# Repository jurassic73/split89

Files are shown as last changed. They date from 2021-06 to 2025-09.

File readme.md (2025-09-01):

# split89 keyboard - a 3d printed 89 key split TKL keyboard base powered by ATmega32U4 Pro Micro controllers with QMK Configurator support.  

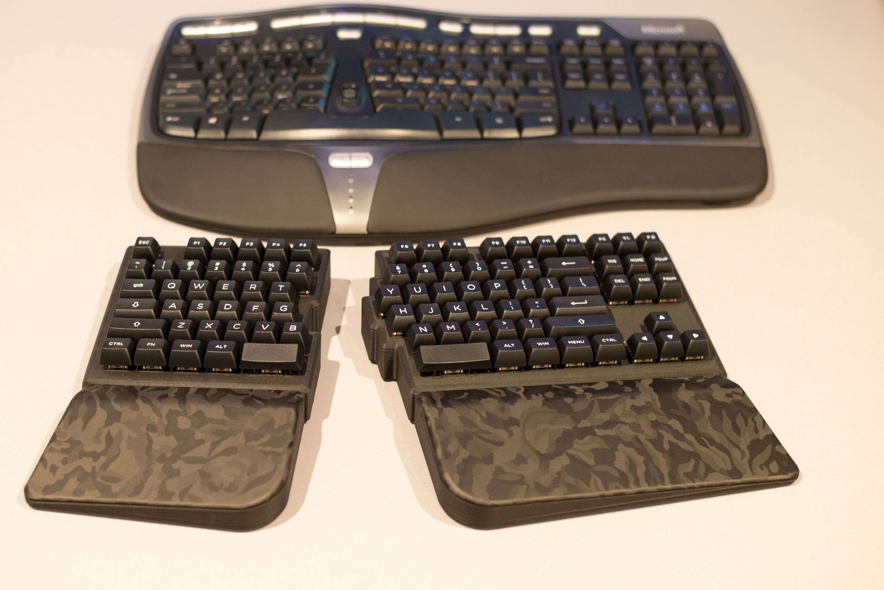
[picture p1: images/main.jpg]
  

This keyboard build was inspired by the Microsoft Ergonomic 4000 keyboard I used for roughly 12 years or so.  I broke my left wrist twice over the years so an ergo keyboard is a must for me to type comfortably all day long else my left wrist starts to burn after a few hours of typing on a regular keyboard.  This is a real bummer since there are so many amazing keyboards out there.  I could not find a split TKL like this layout so I designed one.  I started designing this on Dec 4th, 2020 and built my first version in June 2021. This has a 6° tent and a 3° incline.  I designed this to sit as low as possible with these angles on a table.  One key switch is actually in a recess in the baseplate with a few mm of material below it.

YouTube - Overview Build Videos<br>
[Part 1](https://youtu.be/i7usy5cnMP0) [Part 2](https://youtu.be/8Tm1rYtXKhw) [Part 3](https://youtu.be/rSSixBk8nNw)

The left half has an extra key on the bottom row(vs standard TKL) so you can shift to other layers for more functionality.  The [default keymap below](#programming-the-controllers) illustrates this.  Verify the keycaps you shop for has eight 1.25u keys for this row. You'll also need to source 2.25 and 2.75 space bars. Reversed shift keys often work well in this position and provide your thumbs with a more agreeable landing surface angle.

QMK Configurator support means you can create a custom firmware for this keyboard with your own keymaps/layers or simply download the existing keymap firmware via the [QMK Configurator](https://config.qmk.fm/#/handwired/split89/LAYOUT) page.

Given you have all tools required, you can build this keyboard for roughly $120 in materials minimum that I can find.  My builds were average $150-$200 or so in materials.

What if you don't have a 3d printer?  You may have options... there are print services out there, the [3Dprintmything subreddit](https://www.reddit.com/r/3Dprintmything/) may be of help or your local maker space or check with friends that print(if you know someone).  Rates can vary quite a bit so shop around.  This is no quick print, it takes roughly 77 hours to print all parts.  There are specifics below you'd want said printing help to view before slicing to ensure your parts are printed as needed.  Of course this could be the project that justifies the purchase of a printer of your own! :)

If you're stuck with what to go with regarding colors and materials(there are a ton of options out there for your components), check out my monochrome material list towards the bottom of this page.  Hard to go wrong with a black/white keyboard scheme. Also check out the [Printables split89 Makes](https://www.printables.com/model/75599-split89/comments) for inspiration.

If you wish to redesign/modify any bit of this keyboard, a STEP file ( [split89.step](https://github.com/jurassic73/split89/blob/main/split89.step) ) has been added to the repo for you to download and edit with your CAD software.

A request from me... If you end up building this keyboard, please share your build here as a make! [prusaprinters.org split89](https://www.prusaprinters.org/prints/75599-split89)  Builders have taken customization options in directions I never thought about and it's awesome to see them customize them to their liking. I was happy with the result of this build for my own use and put this document together to share this design and hopefully inspire/help others looking to build a split TKL.  I've built four of these keyboards so far and learned things to adjust and document to refine this build document and videos to dump as much knowledge as I could so the only thing holding back a builder is time and the desired to build. :) Seeing your build would be awesome.

**External Links**  
[QMK Configurator](https://config.qmk.fm/#/handwired/split89/LAYOUT) - keymap/firmware generator  
[prusaprinters.org](https://www.prusaprinters.org/prints/75599-split89)  

**Table of Contents**  
[Bill of Materials](#bill-of-materials)  
[Tool suggestions](#tool-suggestions)  
[Assembly](#assembly)  
1)  [Print keyboard pieces](#print-keyboard-pieces)  
2)  [Install keyswitches and stabs](#install-keyswitches-and-stabs)  
3)  [Prepping the diodes](#prepping-the-diodes)  
4)  [Installing the diode rows](#installing-the-diode-rows)  
5)  [Installing the column wires](#installing-the-column-wires)  
6)  [Wiring the controller, reset button and TRRS jack](#wiring-the-controller-reset-button-and-TRRS-jack)  
7)  [Programming the controllers](#programming-the-controllers)  
8)  [Installing the base plates](#installing-the-base-plates)  
9)  [Wrap the wrist bases and rests](#wrap-the-wrist-bases-and-rests)  
10) [Mount the wrist bases and rests](#mount-the-wrist-bases-and-rests) 
11) [Install rubber feet](#install-rubber-feet)  

**My Personal Builds**  
[Keyboard Pics](#my-personal-build)  
[Main Hardware](#my-personal-build-main-hardware)  
[Tools](#my-tools)  
[GMK Info](#gmk-info)  

# Bill of Materials  
  * 3d printed components in [3d_printing_stl_files](https://github.com/jurassic73/split89/tree/main/3d_printing_stl_files) directory
    **See print notes below! ( [Print keyboard pieces](#print-keyboard-pieces) ) Critical for successful printing!** <br>
    **Print one of each:**  
      split89_electronics_plate_left.stl  (microusb or usbc)
      split89_electronics_plate_right.stl  (microusb or usbc)
      split89_left_body.stl  
      split89_left_body_base.stl or split89_left_body_base_no_pillar.stl *  
      split89_left_wrist_base.stl  
      split89_left_wrist_pad.stl  
      split89_right_body.stl  
      split89_right_body_base.stl or split89_right_body_base_no_pillar.stl *  
      split89_right_wrist_base.stl  
      split89_right_wrist_pad.stl  
    **Print two of each:**  
      split89_arduino_brace.stl  (microusb or usbc)
      split89_reset_button_brace.stl  
      split89_trrs_jack_brace.stl  
        \* Note - there are two versions of the base plates.  The original has bolt holes and a partial pillar to connect to the body in the middle of the large surfaces to couple the base to the main body surface for a tighter sound.  I added base plates that are void of these pillars/bolt holes which decouples the two large surfaces in the middle for a slightly deeper typing sound.  I prefer the latter but a user can try both to see which they prefer.

        \* Note - there are two versions of electronic plates. USB-C and micro USB. There are also two versions of the Arduino brace.

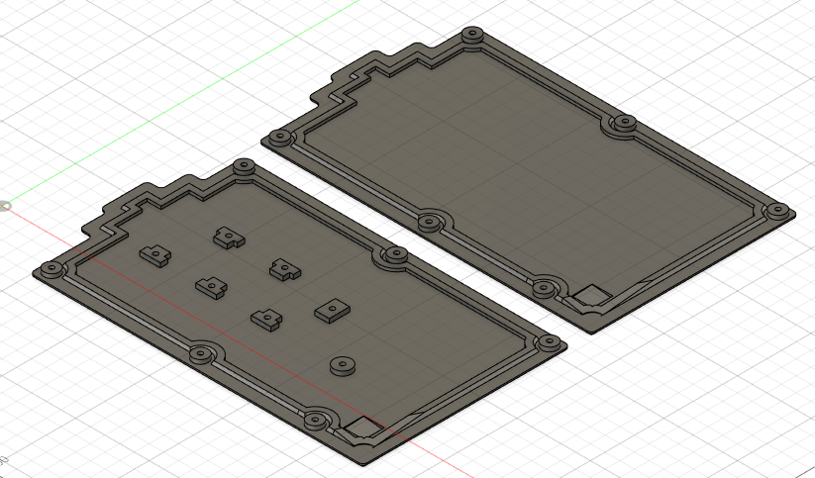
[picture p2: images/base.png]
      
    
  * (2) Pro Micro ATmega32U4 USB-C or USB micro<br>
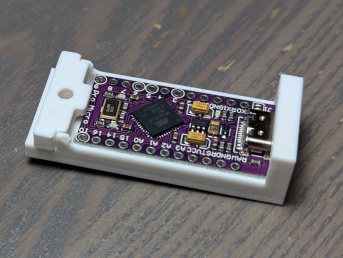
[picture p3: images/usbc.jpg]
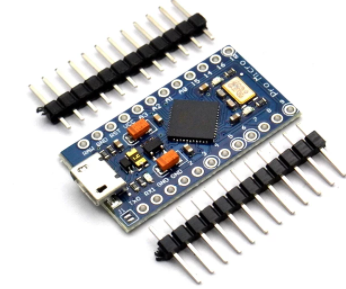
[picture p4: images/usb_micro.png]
     

      A few places to purchase<br>
      * USB-C - [Aliexpress](https://www.aliexpress.us/w/wholesale-pro-micro-usbc-arduino.html)
      * USB Micro - [EBay](https://www.ebay.com/sch/i.html?_nkw=pro+micro+atmega32u4)
      * USB Micro - [Aliexpress](https://www.aliexpress.com/af/atmega32u4.html) (usually cheaper if you have time to wait for slower shipping)

  * (1) 3.5mm TRS or TRRS male to male cable - [EBay](https://www.ebay.com/sch/i.html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) - only three pins in the TRS positions are being used so TRS or TRRS are acceptable to use for connectivity between the halves.  There are some with two 90° plugs if desired for a compact fit. T = tip, R = ring, S = sleeve.
  * (2) 3.5mm TRS/TRRS breakout boards - [Aliexpress](https://www.aliexpress.com/wholesale?SearchText=trrs+audio+socket+breakout) [Amazon](https://www.amazon.com/s?k=trrs+board&Go=Search+Amazon)
  * (1) 2k-10k resistor - [Aliexpress](https://www.aliexpress.com/item/32952657927.html) - a resistor value somewhere in the 2k to 10k range will work.
  * (2) Tactile Micro vertical mount switch (6mmx6mmx8mm total height / 4.5mm button height) - [Aliexpress](https://www.aliexpress.com/item/4000543708838.html?spm=a2g0s.9042311.0.0.27424c4dCLLkyk)
  * (1) USB-C or USB micro cable - only one side needs to be connected to your computer so only one USB cable is required.  I like the magnetic disconnect USB cable I listed towards the bottom of this document.  Make it easy to disconnect the USB cable when needed.  The cable needs to be connected to the keyboard with the LED on the cord plug facing upwards for proper connectivity.
  * (89) key switches - [NovelKeys](https://novelkeys.xyz/collections/switches/products/gateron-switches?variant=37302529851559) - example switch to use - I'm a fan of linear switches.  If you're not sure which key switch type you'd like, there are [key switch testers](https://www.amazon.com/s?k=key+switch+tester) out there to help you make your decision.
  * (6) 2U plate mount key switch stabilizers [Amazon](https://www.amazon.com/gp/product/B096JVL2MQ/) - [Aliexpress](https://www.aliexpress.com/item/1005001543613992.html) - buy a few smaller sets or the one for the 104 keyswitch board to get the (6) required 2U stabs.
  * (87) key caps - [Key cap List](http://www.keyboard-layout-editor.com/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'&_w:2.25%3B&=Enter%3B&@_w:2.25%3B&=Shift&=Z&=X&=C&=V&=B&_x:2.75%3B&=N&=M&=%3C%0A,&=%3E%0A.&=%3F%0A%2F%2F&_w:2.75%3B&=Shift&_x:1.25%3B&=%E2%86%91%3B&@_w:1.25%3B&=Ctrl&_w:1.25%3B&=Fn&_w:1.25%3B&=Win&_w:1.25%3B&=Alt&_a:7&w:2.25%3B&=&_x:2.75&w:2.75%3B&=&_a:4&w:1.25%3B&=Alt&_w:1.25%3B&=Win&_w:1.25%3B&=Menu&_w:1.25%3B&=Ctrl&_x:0.25%3B&=%E2%86%90&=%E2%86%93&=%E2%86%92) - most standard keycap sets will work fine but ensure they have eight 1.25u keycaps.  Some only have seven.  I'm a big fan of the [AKKO keycap sets](https://en.akkogear.com/store/keycap/) in ASA profile which is like a cherry MX but slightly sculpted(Much less than SA profile) in both directions vs cylindrical.  They have more color sets on their site vs Amazon.  Amazon has a good return policy if you want to order them and just see them in person to see if you like them.
  * (2) space bar keys - 2.25u / 2.75u - As noted above, beyond the standard keycaps, you'll need to either source 2.25u/2.75u space bars(which can be tough) or just use shift keys for your space bars (2.25u and 2.75u) in reverse orientation.  Most keycap sets don't come with 'extra' space bar caps so I like to use these blank shift keys for space bars. The face angle of these shift caps, installed in reverse orientation, is really agreeable for your thumb to land on. They look odd at first, but once you try them in this orientation, I feel you will not want to change them.
  
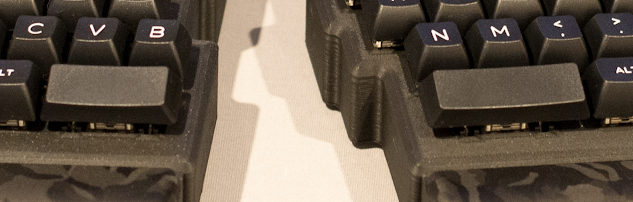
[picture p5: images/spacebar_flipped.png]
    
  
    They are only available in ABS so they will take a little shine over time but they're a comfortable compliment to my AKKO ASA sets and come in enough colors to get something close or at least neutral in color vs your primary keycap set.  They're also the most reasonable cost I've found out there at $2.50 per individual cap.  WASD can custom print items on your caps but I found that print wears off in time so I stick with blanks from them.
  * Wire - 6 color pack on [Amazon](https://www.amazon.com/gp/product/B07V1D82HM/) - 24AWG pre-tinned wired - color helps you keep track of what's where.  Solid core and pre-tinned as well so soldering is easier. 
  * (89) 1N4148 Diodes - 100ct pack - [Aliexpress](https://www.aliexpress.com/af/1N4148-do%25252d35.html) - [Ebay](https://www.ebay.com/sch/i.html?_nkw=1N4148++do-35)  
  * M3 Hardware  [Amazon](https://www.amazon.com/s?k=m3+hardware) - [Aliexpress](https://www.aliexpress.com/item/10000150053486.html)  
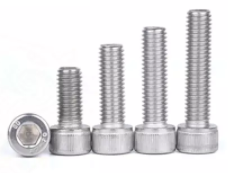
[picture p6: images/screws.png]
    
    (6)  20mm  
    (34) 10mm  
    (5)  8mm  
    (3)  6mm  
    (6) washers  
    (6) nylock nuts  
  * Car wrap vinyl - [metrostyling.com](https://metrorestyling.com/pages/3m-vinyl-wrap) or [Ebay](https://www.ebay.com/sch/i.html?_nkw=carbon+fiber+vinyl+wrap+3M) - for covering wrist rest pad pieces.  The 3d printed surfaces are rough and can hold stuff so putting this on makes them a more comfortable contact surface and easy to clean.  There are videos for applying with a heat gun/hair dryer to soften at the corners to stretch around them for a smooth finish.
    (2) 8 1/2" x 11" sheets
  * (18) Rubber feet - [Amazon](https://www.amazon.com/gp/product/B00K6RZ9Q2/) - 144 pack

# Tool suggestions  
  These tools are not required but certainly make the build easier and come in handy on most electronics projects
  * [Micro flush cutters](https://www.amazon.com/s?k=micro+flush+cutters) - these not only cut wire but have one side flattened so you can cut items flush with a surface like on the back of the Pro Micro where some wires may be sticking out beyond the solder.
  * [Tweezers](https://www.amazon.com/s?k=electronics+tweezers) - there are a ton of options out there.  Something with a long narrow end and serrations for grip are very handy to move things around or hold them in position while soldering.
  * [Blue tack](https://www.amazon.com/s?k=blue+tack) - this stuff is typically used to mount things on other things like cardboard or paper but a chunk works great to hold things in position while you solder.  Just don't heat up objects too long or it can get a little sticky.
  * [Vice](https://www.thingiverse.com/thing:2064269) - great tool to have in your toolbox for holding small items like the TRRS and Pro Micro boards when soldering.

# Assembly

### Print keyboard pieces

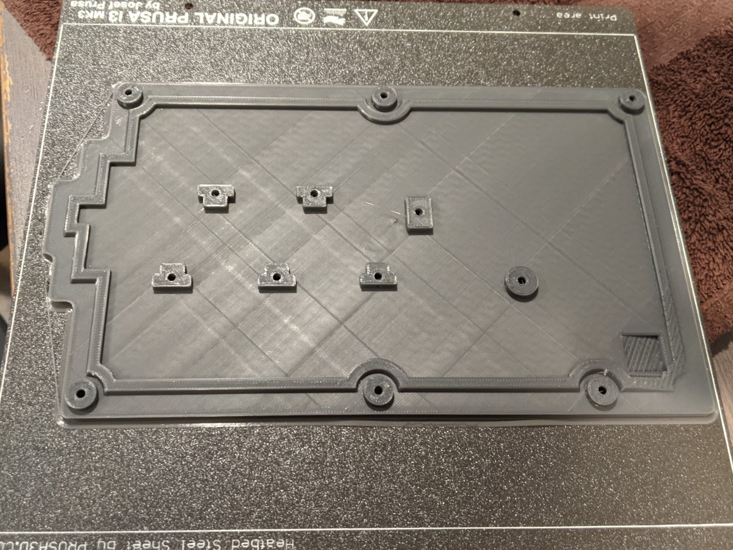
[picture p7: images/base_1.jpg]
  

  I've built four of these keyboards now.  One using SunLu Gray PETG and three using Eryone Matte PLA.  PETG is less rigid vs PLA and holds it's shape better over time under pressure like a bolted assembly vs PLA however this Matte has performed well as well and I would easily recommend it along side PETG and it prints easier.

  All pieces were printed using .2mm layer height.  All .stl files should be printed as oriented.  No supports with exception of the wrist rests which use a bit of support material but I found it was the best orientation for the cleanest contact surface possible.

  You should only need one roll of filament for the exposed color pieces.  That is, if you're covering your wrist pads with vinyl, you should be able to print your wrist bases, bodies, body bases and electronic plate parts out of a single roll of filament and your wrist pads with whatever other color since you're covering them up with vinyl.

**Keyswitch Hole Test Print**

I've added a split89_keyhole_test_print.stl model with a 13.9mm square hole.  Configure your slicer per the below notes, including EFC settings, and print this test piece to ensure your key switch fits correctly in this hole before printing the larger pieces.  Test fit that your key switch installs but isn't deformed or overly tight.  When you look at this printed model, the inside dimension should be 13.9mm square, and the interior walls should be flat, bottom to top, with no bulge/lip(which would indicate an Elephant foot is present).  If the interior walls are flat, bottom to top, you should be ready, with these settings, to print your larger pieces.

**Body Piece/Base Print Notes**

    split89_left_body.stl  
    split89_left_body_base.stl or split89_left_body_base_no_pillar.stl  
    split89_right_body.stl  
    split89_right_body_base.stl or split89_right_body_base_no_pillar.stl  

  **Surface Texture** - The body pieces have the most visible surfaces and I preferred to use a textured print plate as that textured surface hides print lines really well and if you scratch it over time, the texture can kinda hide that wear.  
  
  **Surface Prep** - Unless you know your pieces will stick well, wash your build plate before printing each of these with Joy or Dawn dish washing soap.  This seems to remove all PLA residue for me and ensures a clean print.  You're gonna be staring at this top surface of the body the most, ensure you get a good print with good adhesion.
  
  **PLA** - print bed at 60C helped ensure minimum warping.  I printed at 215C nozzle temp with the matte PLA.
  
  **PETG** - I used the default settings - I had some lifting in the corners.

  **Perimeter** - default 2 or 5 - I changed the perimeter count to five from the default 2 in my slicer for the body pieces as well.  I wanted heavier/denser pieces so my bases didn't sound so hollow.  

  **Brim** - do no use - not needed with good bed adhesion and will cause issues as you need to disable Elephant Foot Compensation(EFC) so the brim attaches to the body correctly(currently the state with Prusa Slicer) but disabling EFC will cause major issues with your key switch holes(see next note).

 **Elephant Foot Compensation** - leave enabled/required  The designed printed key switch holes are 13.9mmx13.9mm.  A key switch is 14mmx14mm.  This .1mm designed difference creates a nice friction fit to secure the switch without deforming it.  Without EFT, any bit of resulting elephant foot deformation interferes with this design and can affect switch operation.  I found this out the hard way during one of my initial prints by disabling EFC. My switches were either too tight when installed and they were deformed and it bound up the stem or the elephant foot was so much in one area of one of the bodies, that I could not insert my switches.  **Keep EFC enabled.**
  
  **Support** [easy to remove support settings](https://projects.ttlexceeded.com/3dprinting_techniques_removable_supports.html) - supports for this build are only needed for wrist pad pieces.  The supports can be very tough to remove easily/cleanly from wide surfaces however I use the settings in the link.  The supports,created with these settings, remove relatively easily/cleanly without much effort.
 
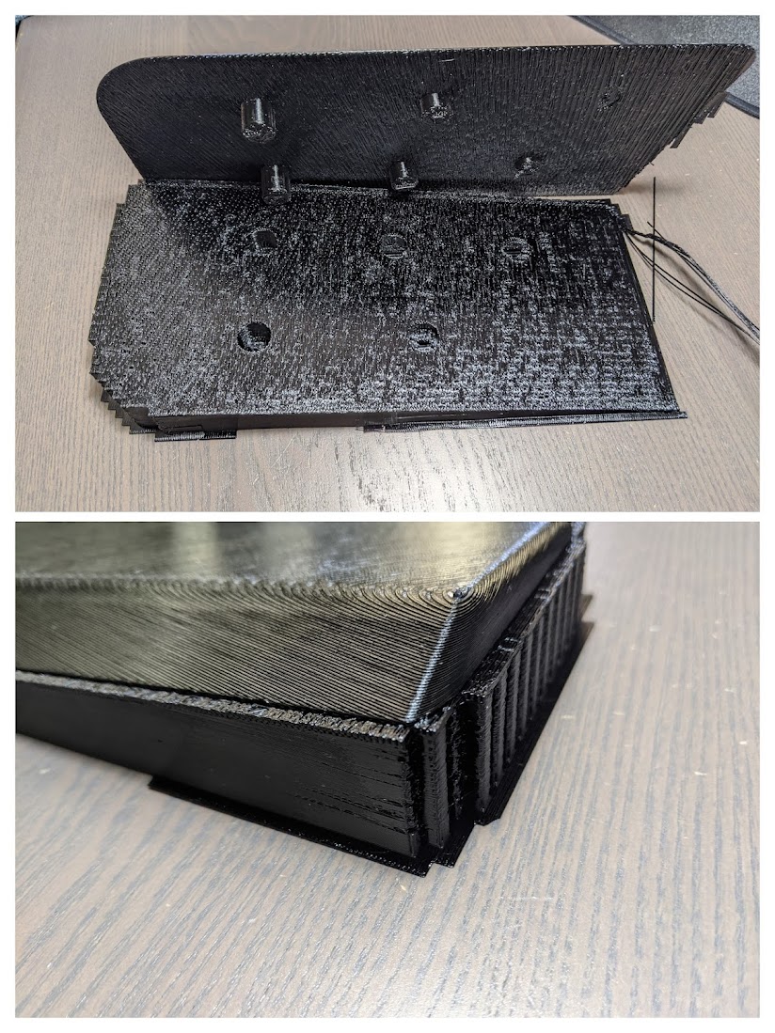
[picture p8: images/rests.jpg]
 
 
 The remaining pieces for the wrist pads/bases and electronics plates I printed using the default Prusa slicer settings for PLA or PETG respectively.
  
### Install key switches and stabs

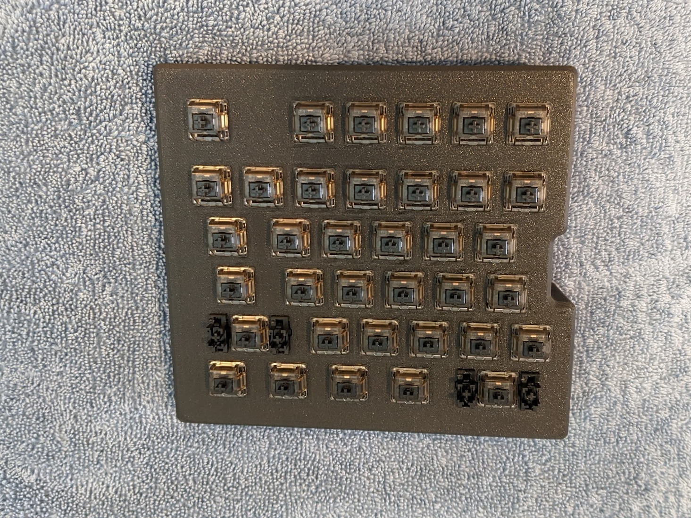
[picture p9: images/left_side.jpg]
  

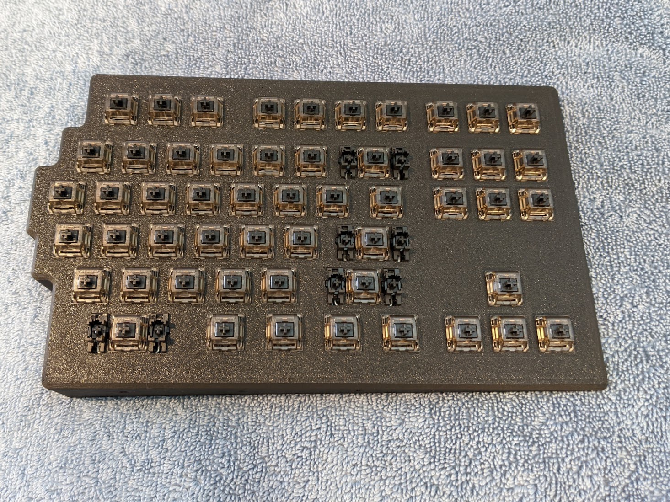
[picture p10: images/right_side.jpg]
  

  This keyboard has 13.9mm square holes for the key switches.  The key switches should press into place firmly.  The stabilizers insert and kinda rotate into their position as they are fully seated.  I took the time to disassemble and lube my key switches using Super Lube prior to installation.  Also added lube to my stabs.  This is not required but the few hours you put in to lubing your switches will be noticeable over many hours of use.  There are many videos out there on how to do this.

### Prepping the diodes

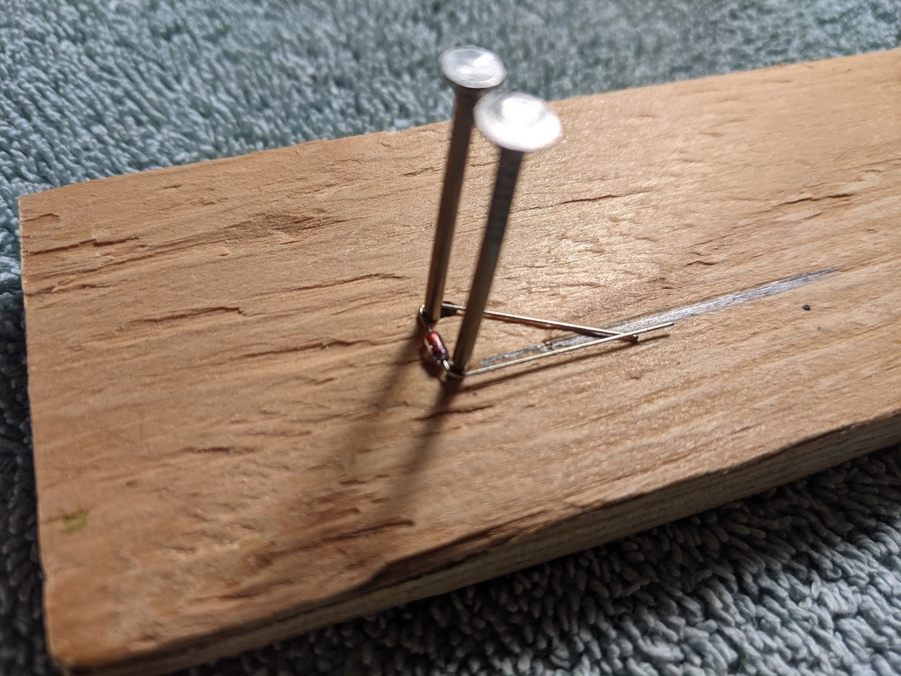
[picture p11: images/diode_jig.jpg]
  

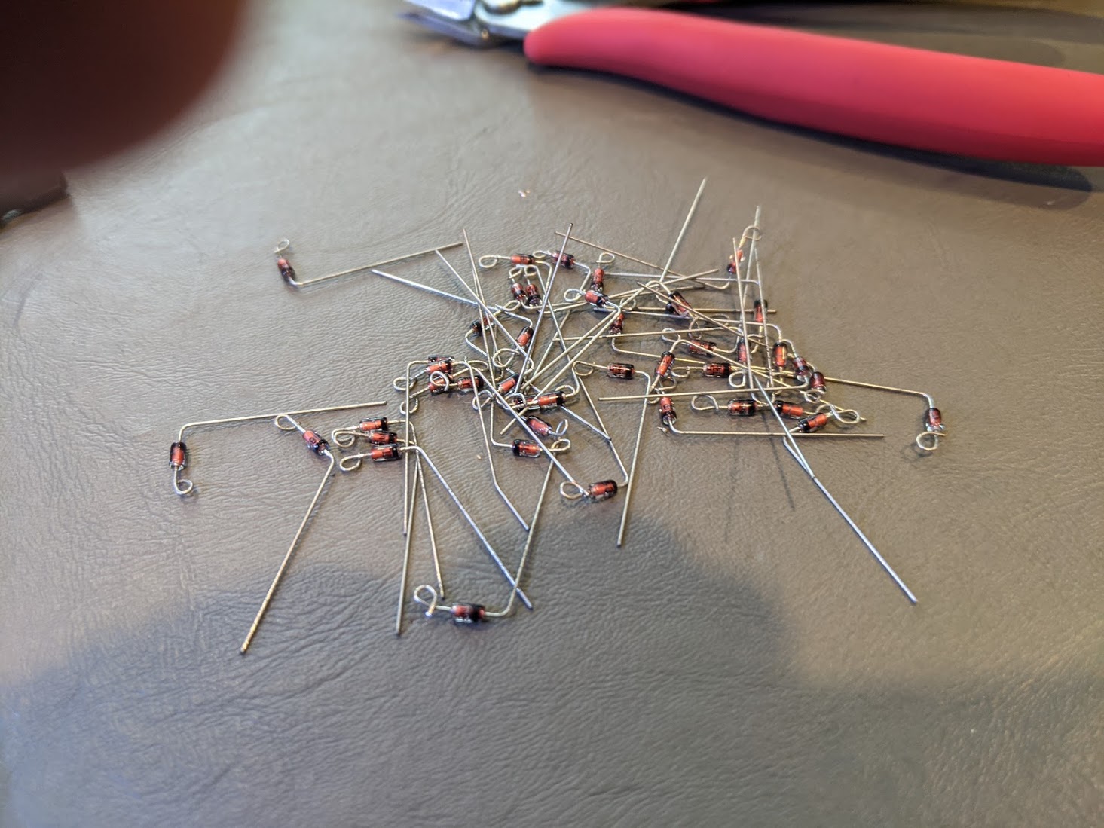
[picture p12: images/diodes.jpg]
  

  For an easier installation and cleaner final result, I opted to put a few nails in a board(1 cm apart center to center) with a line perpendicular to the nail's alignment, to help me put consistent 90 degree bends in them at the right lengths.  The bottom will get a 90 degree bend. The top gets a 90 as well but then you'll use a pair of needle nose pliers to make a loop.  This loop will go over one of the legs of the switches for easier soldering.  Ensure that you have the black marked end of the diode facing the 90, not the loop.  This is critical for your keyboard to operate.  One of my diodes was backwards and the key at that location would simply not work til I fixed the diode orientation.

### Installing the diode rows

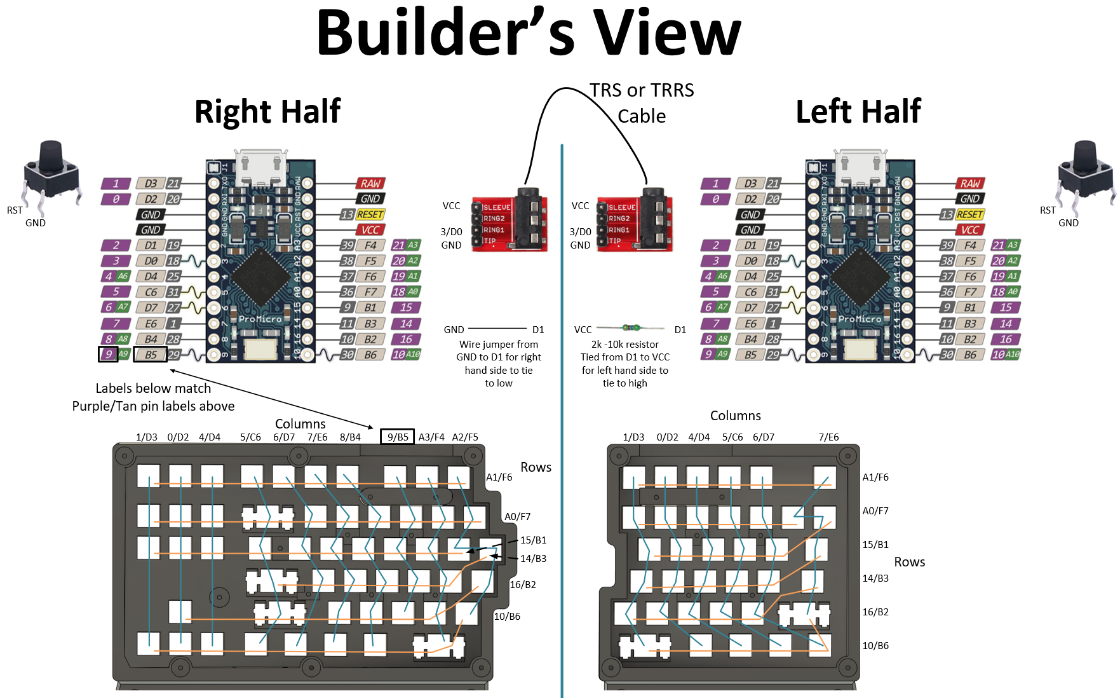
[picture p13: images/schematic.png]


  Each key switch requires a diode.  I installed these one row at a time.  I would put all diodes in place for the row I was soldering.  The diode at the far right column had it's 90 leg snipped short.  Once all are laid in place, solder from left to right.  I used the cut off legs to cover the distance between the keys in rows that were further apart for appearance.  You could just jumper these spans with wire as well.

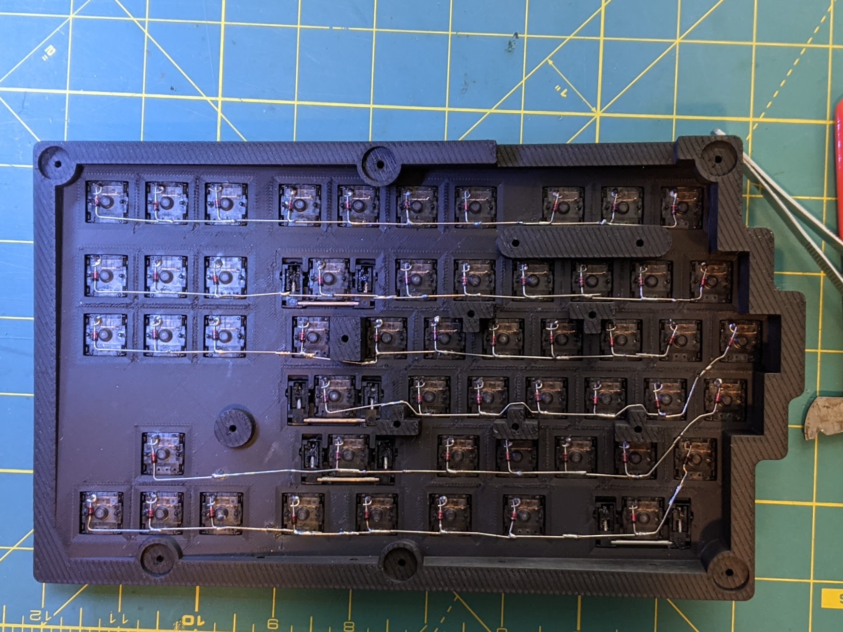
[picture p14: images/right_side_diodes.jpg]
  

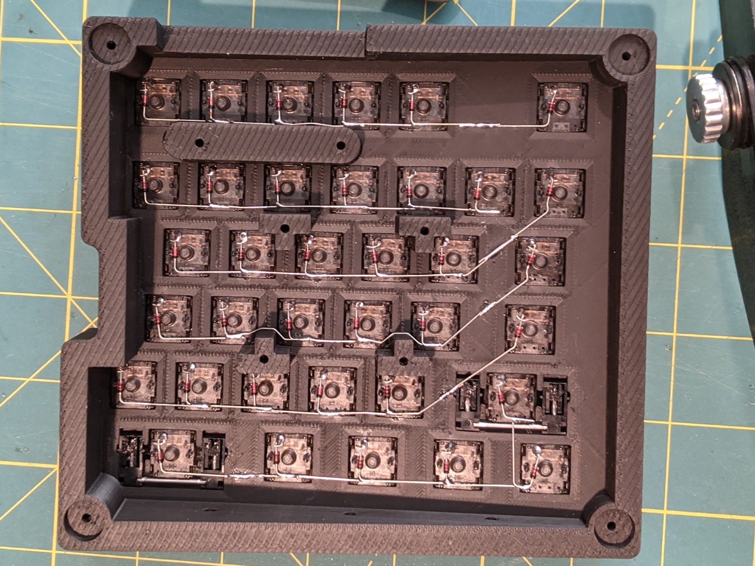
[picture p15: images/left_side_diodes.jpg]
 

### Installing the column wires

  Per the diagram, using insulated wire, you will solder the 5-6 pins per column together.  To do this, I would cut 8" pieces at a time.  Easiest way is to just pull all six colors at once and cut them together.  Remove 1/2" of insulation from one end and make a loop similar to the diodes.  Put this on the pin of the switch at one end of the column.  Next, you'll need to figure out where you need to expose the wire.  I'd put the wire on the first pin and then bend the wire where the next pin is located.  I used a set of wire strippers(which you can set how far they close) to cut the jacket(not the wire) and then, holding the looped end, pull the insulation a bit to expose 1/4" of wire.  I'd repeat threading the wire in place to find where to cut and eventually end up with a piece of wire with gaps where I needed to solder.  Some folks use an x-acto knife to open the wire insulation where needed.  Others use a soldering iron to just melt the jacket away.  At any rate, you'll build these column wires and solder them into place per the diagram.

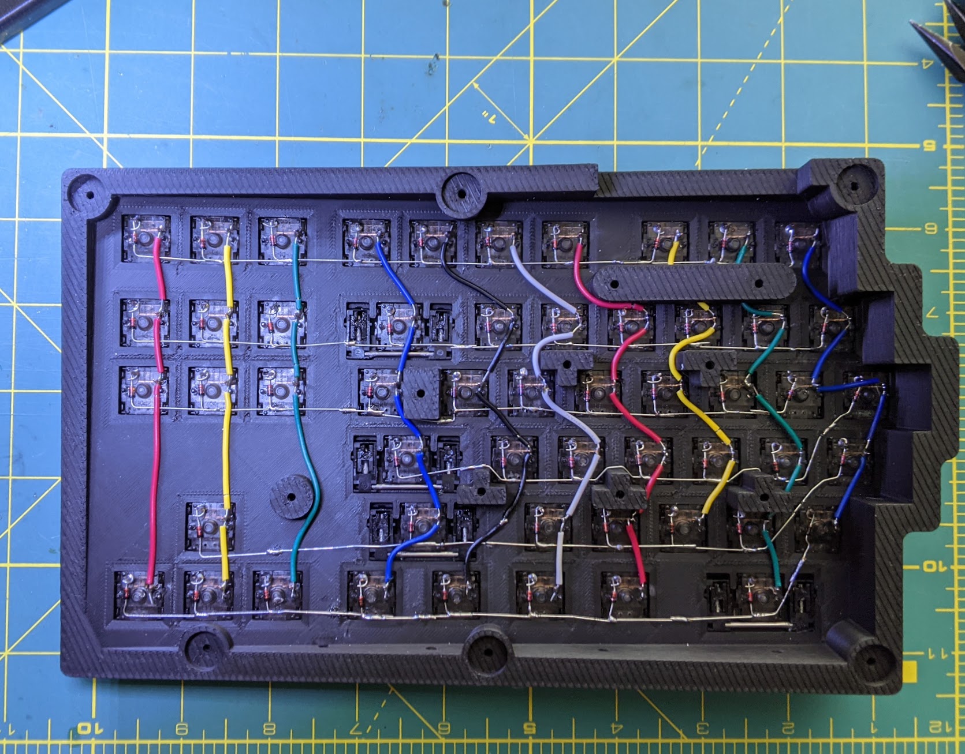
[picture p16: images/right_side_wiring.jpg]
  

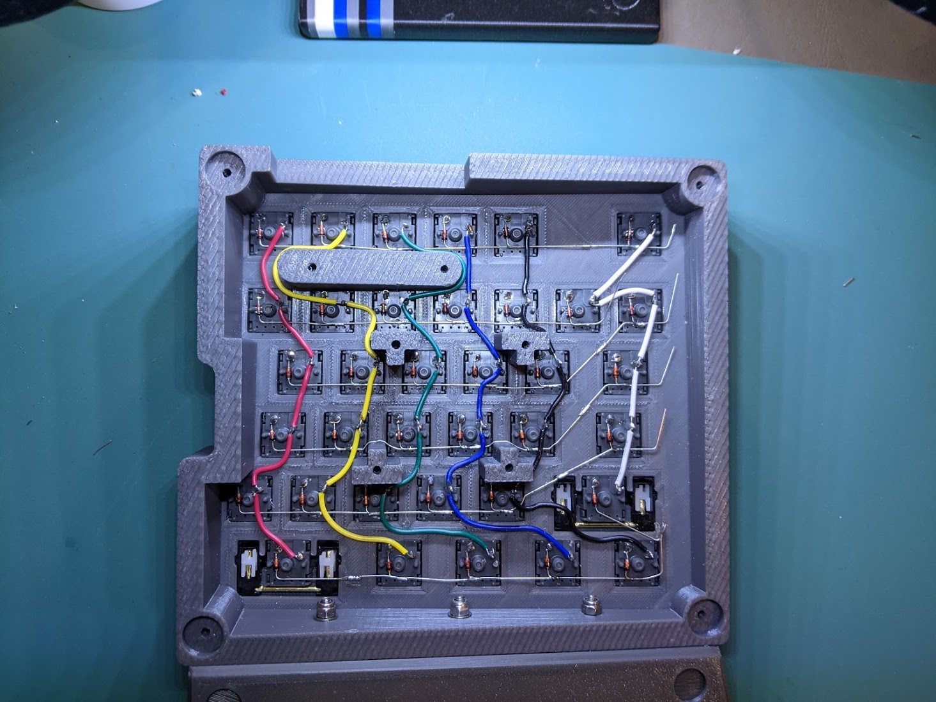
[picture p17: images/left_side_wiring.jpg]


### Wiring the controller, reset button, TRRS jack, jumper and resistor
  
  Note: keep good length wires to the reset switch, TRRS jack plate and off to the matrix from the controller in such a way that you can route them to lie flat enough so you can properly install the base plate.  Note the base plate has a rim as well.  If the wires are stacked too high, you won't be able to install the base plate correctly (made this mistake myself and had to install longer wires so they could route properly to lay flat).

  The tactile reset switch is not directional.  i.e. the two wires connecting to them just need to connect to two contacts that come out the same side of the switch.

  I would highly recommend putting all jumpers required, in place on the pro micro, before mounting the pro micro on the electronics plate.   If the pro micro boards are a snug fit, you can either sand or scrape the edge of the PCB (exposed edge next to the pins) lightly and then try refitting.  I found that most of my boards installed fine while I had two that had somewhat rough edges which didn't allow them to slide in to place.  After scraping the edges a touch, they slid in to place on the electronics plates fine.

  **NOTE**: if you find the USB-C board slides after the brace is in place, put a piece of electric tape between the board and brace to make up the difference. There may be up to 1mm variation in your USB-C board length.

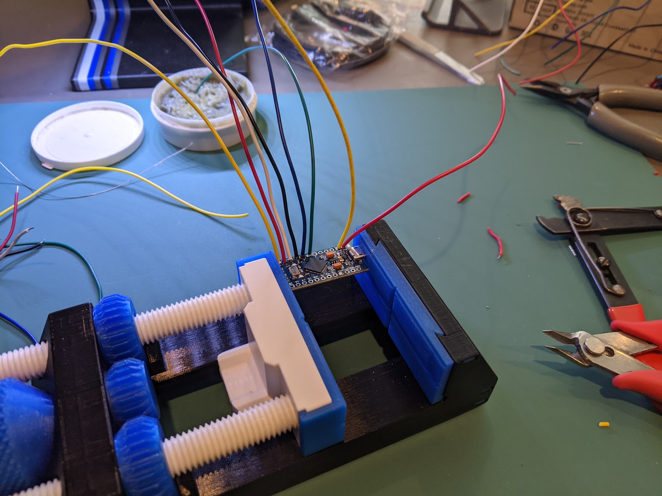
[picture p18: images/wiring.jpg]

  
  Also, note which plate goes with with which controller, right or left.  They are specific to each side.  The right side has more wires.  Pre-wiring the controllers will make for an easier and cleaner installation.  I tinned all of the pins on the controller I'd be using ahead of time.  The pre-tinned wire drops into place nicely when these tinned pins are reheated.  
  
  The pins on the pro micro need to be connected to the respective rows and columns of the keyboard matrix.  They can be connected at any point of the column or row.  On the row connection, connect to the common connection across all diodes, not on the switch side of a diode.
  
  I cut 8" wires again, six at a time, to connect to my pro micro and then tied them to the matrix as you can see below.  I had some scrap left over but it's worth it for ease of install to ensure everything can reach with slack to give you routing options.

  There is a jumper and resistor that need to be installed on the pro micro boards to tie pins to high and low.  This is done so the pro micro boards know which they are expecting to be wired to, to apply the firmware accordingly to what you've wired out(left side or right side).  The wire jumper ties it's pin low to ground(right half).  The resistor ties it's pin high to VCC(left half).  

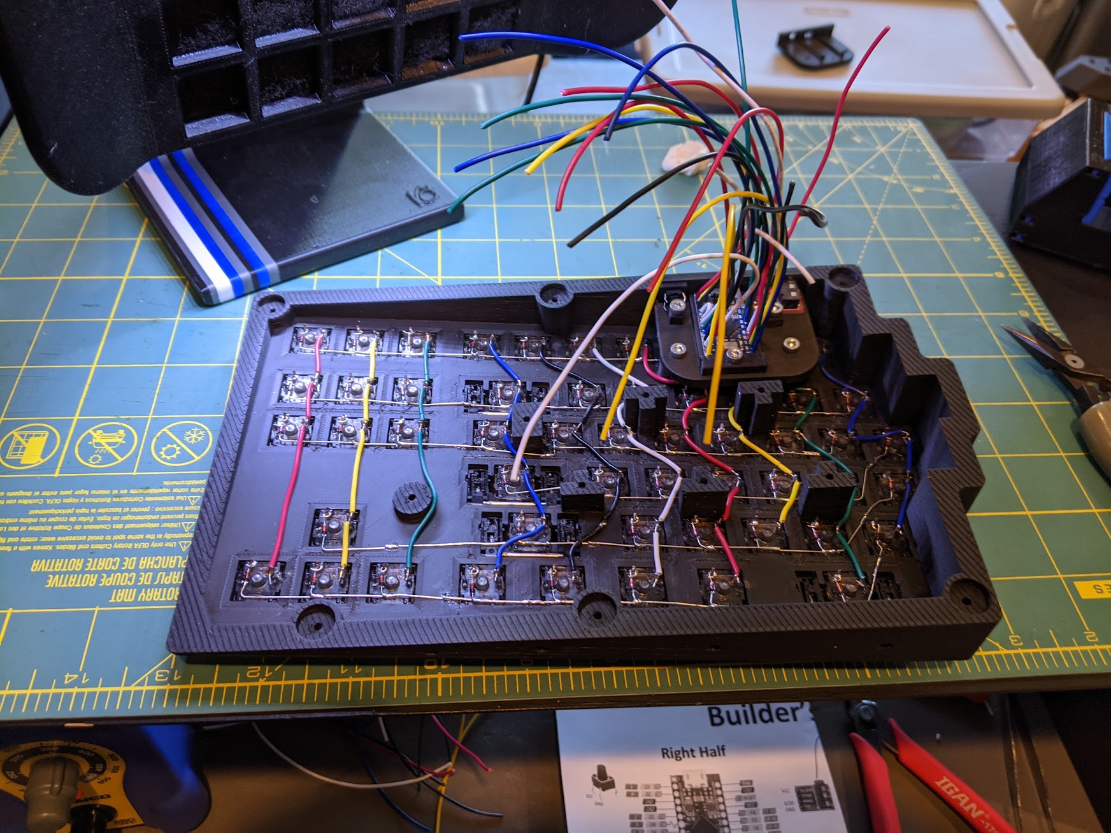
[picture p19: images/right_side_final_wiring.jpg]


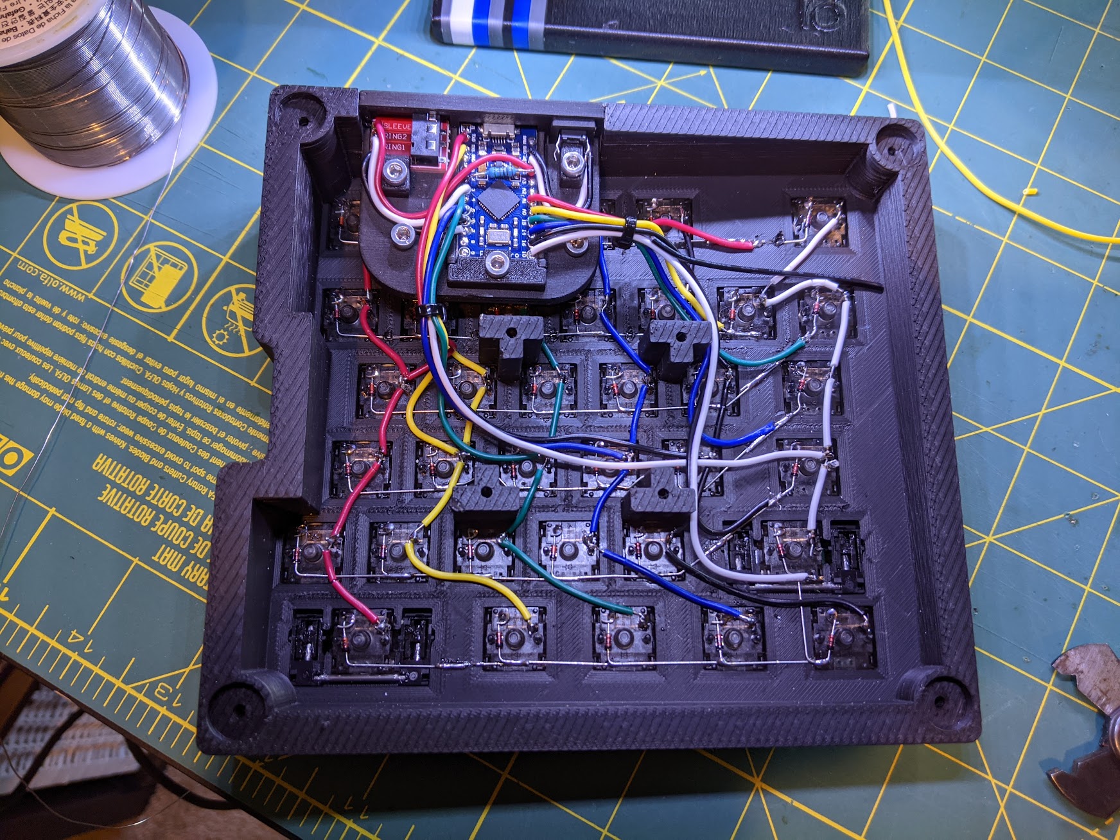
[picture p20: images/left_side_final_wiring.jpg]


### Programming the controllers

  **Download Firmware**

  **NOTE:** working firmware hex file [here](https://raw.githubusercontent.com/jurassic73/split89/main/split89_default.hex). Right click link and save as.

  If you wish to customize your firmware with different key functions go here to remap some new functions and download your custom keyboard mapping firmware! :)

  [QMK Configurator](https://config.qmk.fm/#/handwired/split89/LAYOUT)  
  
  To download the default layout firmware, go to the above QMK link, click 'COMPILE' in the upper right corner and you'll see a popup noting that firmware is being compiled.  Once the firmware generation is complete, click the 'FIRMWARE' button to download the hex file.  The reason you download from this page is so if you want to customize the keymap, you can do so.  There are different colorways to view different color schemes.  These colorways do not affect the keymap.
  
  **Install Firmware Using QMK Toolbox**

  Next, download and install QMK Toolbox.  You will use this to flash the hex file onto the controllers.  
  QMK Toolbox - [wiki](https://github.com/qmk/qmk_toolbox) - [downloads](https://github.com/qmk/qmk_toolbox/releases)  
  
  The below assume all goes smoothly.  If you encounter a roadblock, check the wiki link above for further information.

  Start up QMK Toolbox  
  
  At the top, select Open, navigate to the hex file you downloaded and select it.
  
  Connect one of the halves of the keyboard to your computer via USB.  
  Then press the reset button twice quickly and wait a few seconds, you should see a message that your controller is connected and visible to QMK.  
  
  In QMK, click the flash button in the upper right corner.  

  You should see status messages scroll past and then a success message.  

  At this point, your keyboard half should function.  Go [here](https://config.qmk.fm/#/test) to test all keys on this half.

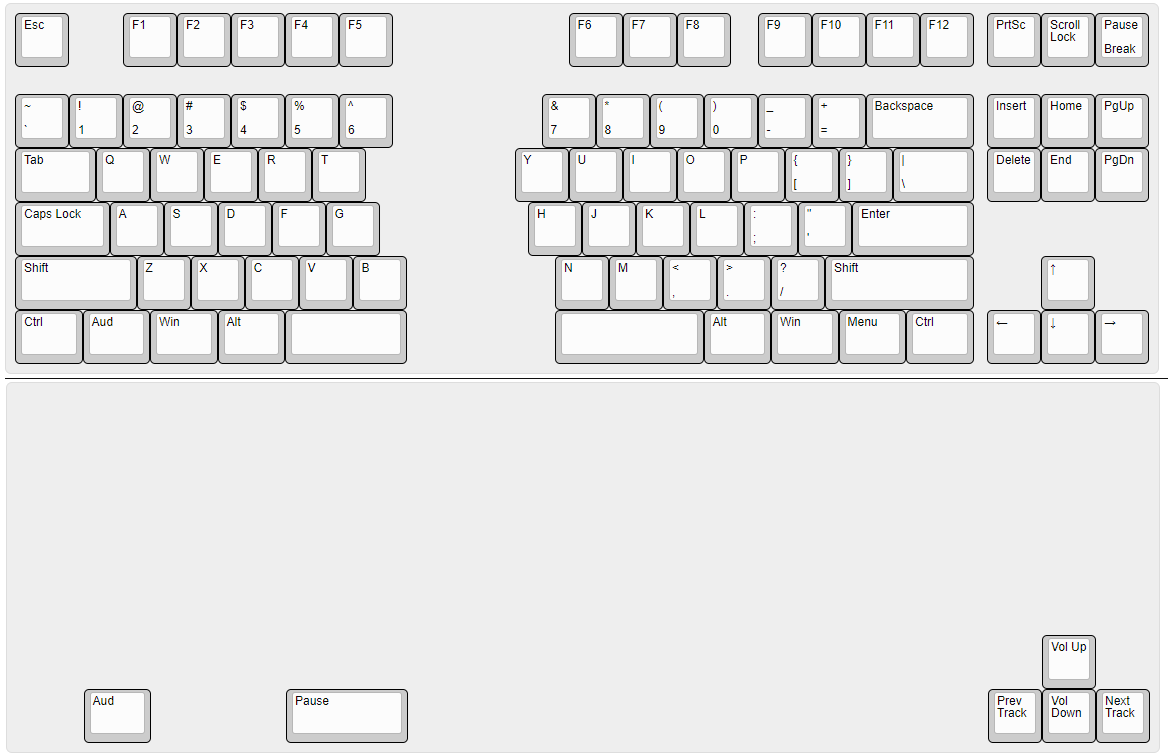
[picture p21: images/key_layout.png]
    

  This firmware is written such that you can upload the same hex to both sides and the pins you tied high and low help the controller identify which side is left and which is right to run the correct part of the keyboard matrix.

  What if a key is not working?  
  - check for a loose soldering connection  
  - check for a reversed diode  
  - if you have a multimeter, check that the switch closes(creates a connection between the pins) when depressed  
  
  My two issues were... I had a connection on my diode rows that was not soldered(was able to move the diode leg with a tweezer).  I also had one reversed diode.  Both quick fixes!  

  Once the second half is flashed successfully, connect the TRS/TRRS cable and ensure that both keyboard halves function correctly via a single USB connection.  The keyboard can function with the USB cable connected to either half of the keyboard as long as the TRS/TRRS cable is in place.  

  Once you've verified both sides are fully functional, pat yourself on the back for a job well done on the wiring and programming!  

### Installing the base plates

  M3 screw size

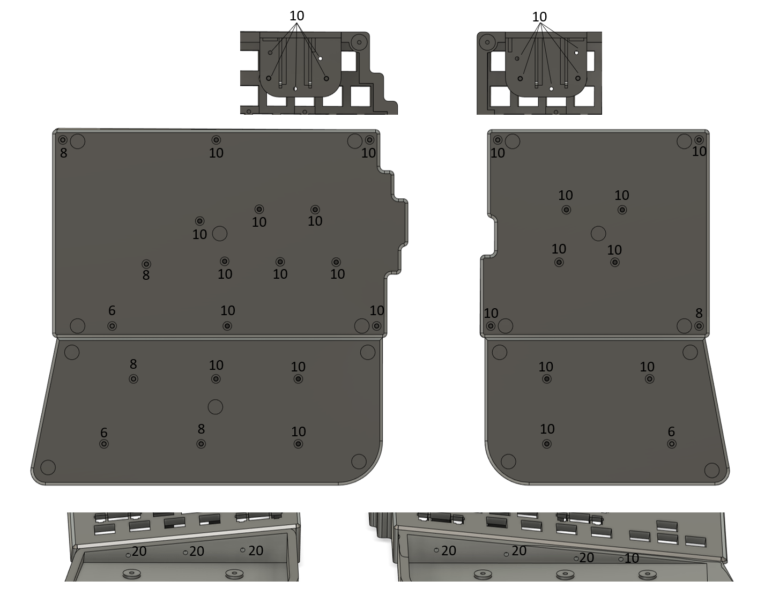
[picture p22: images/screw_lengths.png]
  

  You can install the base plates at this point knowing your keyboard electronics build is fully functional.  I created many joints between the base plates and the main bodies(hence all the screws) to minimize the drumming sound of a large surface with nothing below it.  Especially with plastic vs say aluminum.  
  
### Wrap the wrist bases and rests
  (optional but highly recommended)  

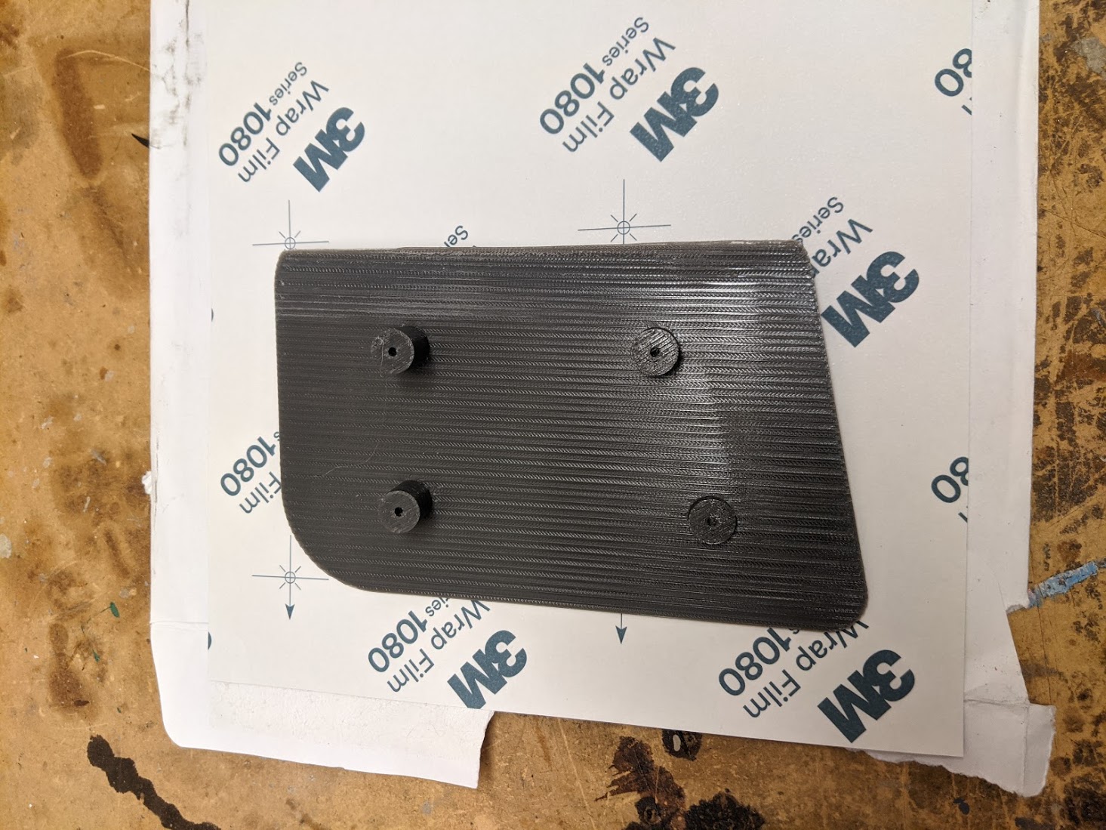
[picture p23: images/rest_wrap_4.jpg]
  

  I used 3M car wrap vinyl I got off EBay.  There are many colors out there.  I went with 3M carbon fiber wrap.  I cut my pieces to leave about 1" extra all the way around so I had something to hang on to while pulling it in to place.  

  The vinyl will cover up tiny gaps and the like in the surface but larger surface texture or bumps will show through.  I sanded down my surfaces with 120 grit sandpaper to knock down most of the top texture.  This made the vinyl lay down nice and flat.  Check the bottom of the pads to ensure they're flat for a good mount to the base.  I then wiped down all surfaces the vinyl would touch with isopropyl alcohol to ensure good adhesion.  

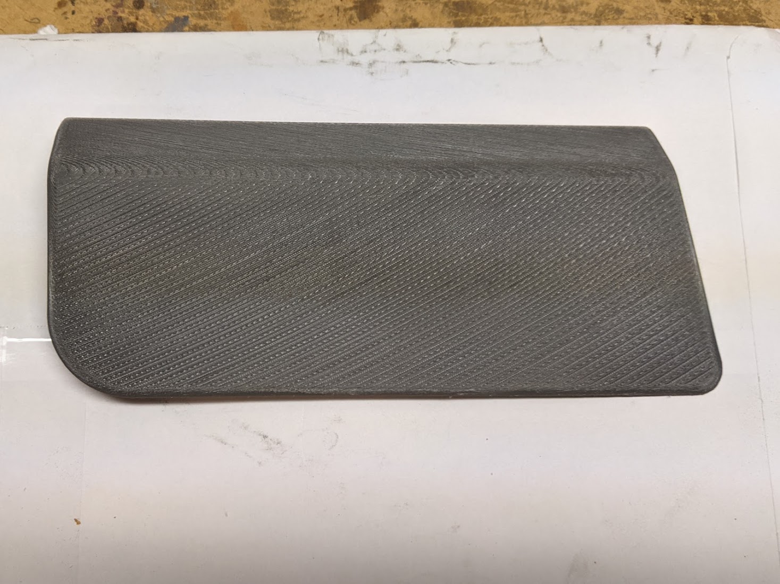
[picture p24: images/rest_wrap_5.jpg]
  

  When you're ready to put the vinyl on, remove the backing and place the vinyl on a clean work surface adhesive side up.  A clean work surface will help ensure no particles or the like make it's way onto this sticky vinyl else you'll see it when you're finished and then it's too late to remove.  This vinyl adhesive side being face up will allow you to easily hold the pad over the vinyl to ensure the bottom edge of the vinyl is parallel to the front edge of the pad so the texture of the vinyl runs straight across the pad.  

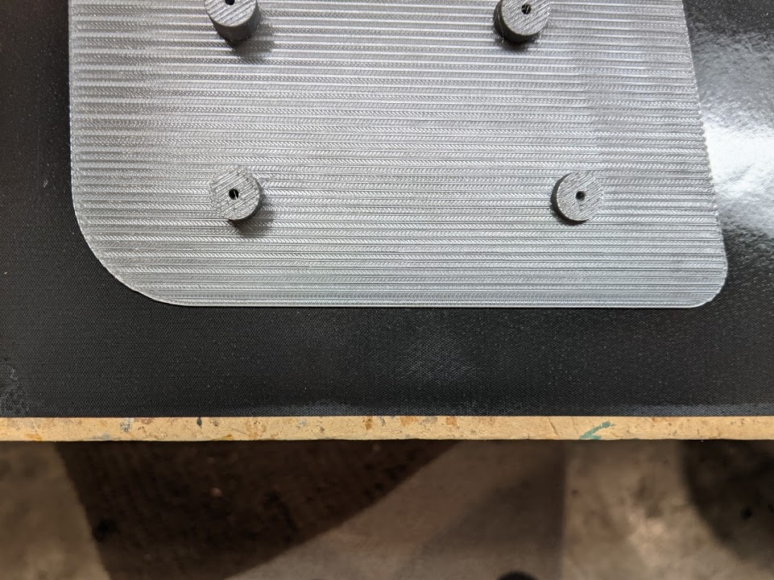
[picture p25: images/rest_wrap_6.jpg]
  

  Set it down on the vinyl and then pull up the long straight edges.  Avoid the corners until you add heat.  

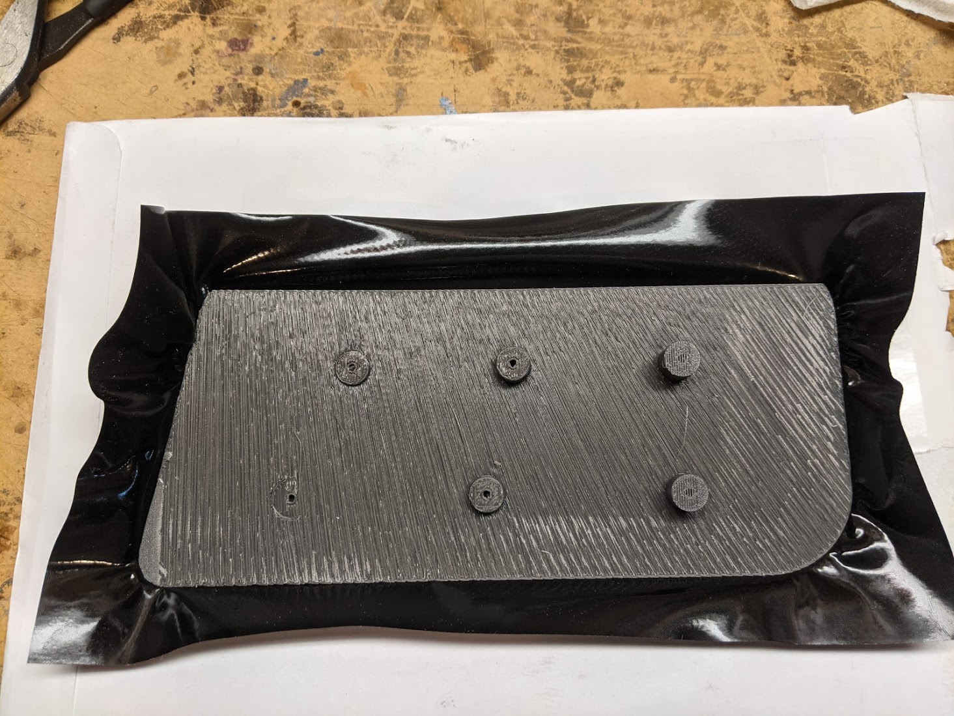
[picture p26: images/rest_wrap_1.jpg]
    

  This is when you'll want to start using heat to pull and lightly stretch and form the vinyl around the edges.  The heat really loosens up this material quickly.  If you're nervous, try practicing with some of the left over vinyl to get a feel for it before mounting your main pieces.  Once I have it pulled up around the edges, I trim it so there's about 1/4"-1/2" of material to fold over on the bottom.  Heat up the bottom and press that edge down as flat as you can.  This will ensure a clean look when installing the pads.

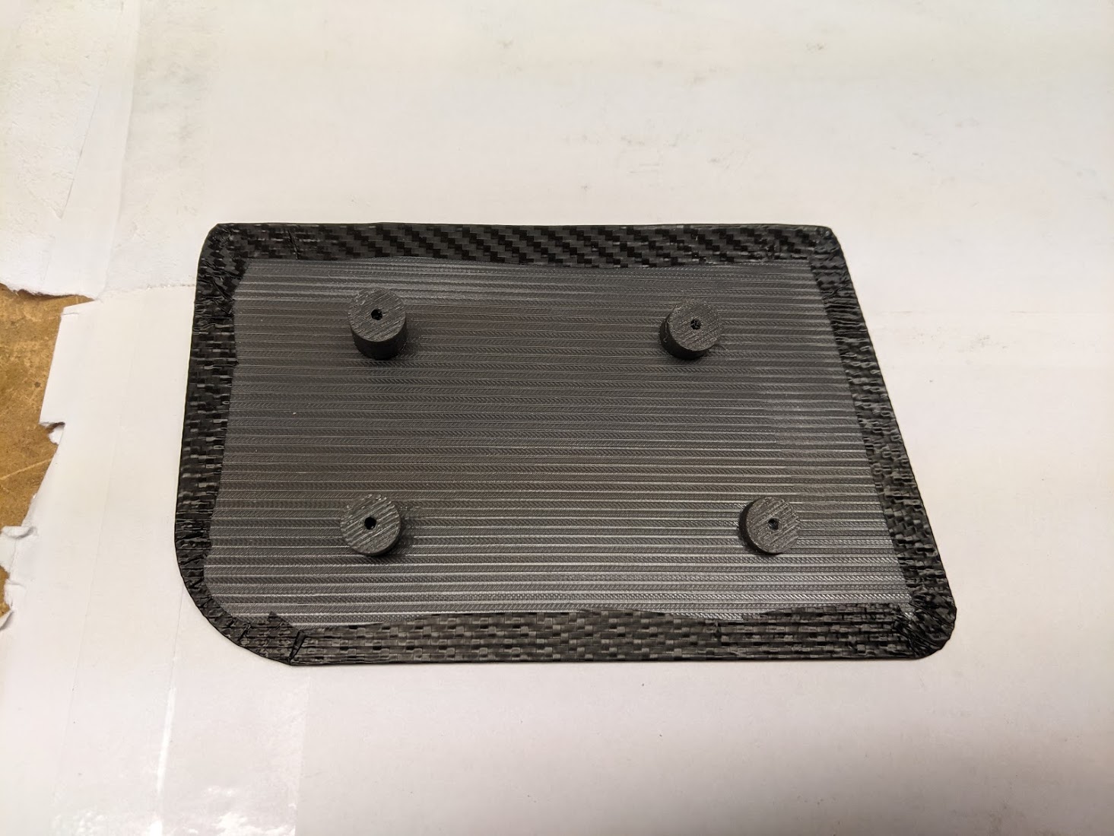
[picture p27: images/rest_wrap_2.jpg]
  

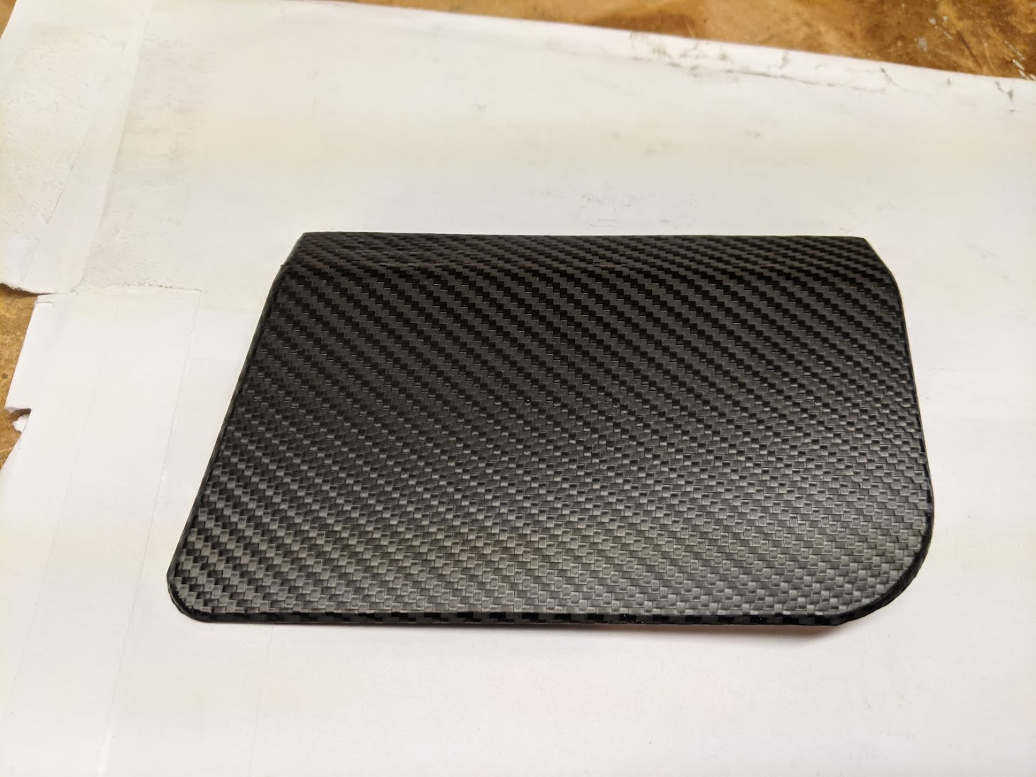
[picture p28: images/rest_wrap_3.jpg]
  

### Mount the wrist bases and rests

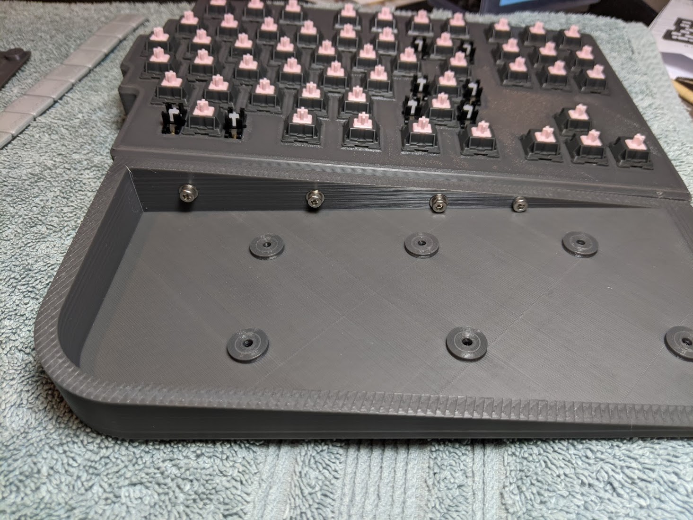
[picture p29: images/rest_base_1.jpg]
  

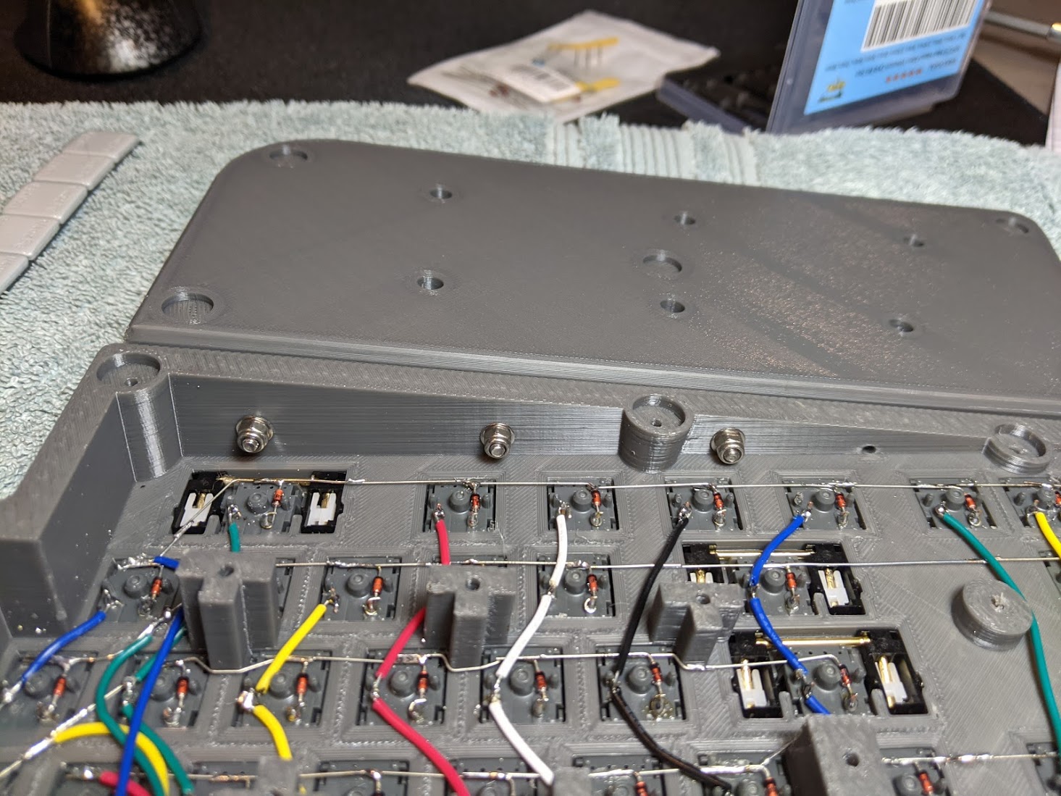
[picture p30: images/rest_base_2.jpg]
   

  The wrist bases are secured to the bodies with  bolts and nylock nuts minus the single 10mm screw which self threads into the body only.

  Mount the wrist rests on the bases.  Note there are a few screws that only purchase a few threads so tread lightly to install those.  
  
### Install rubber feet

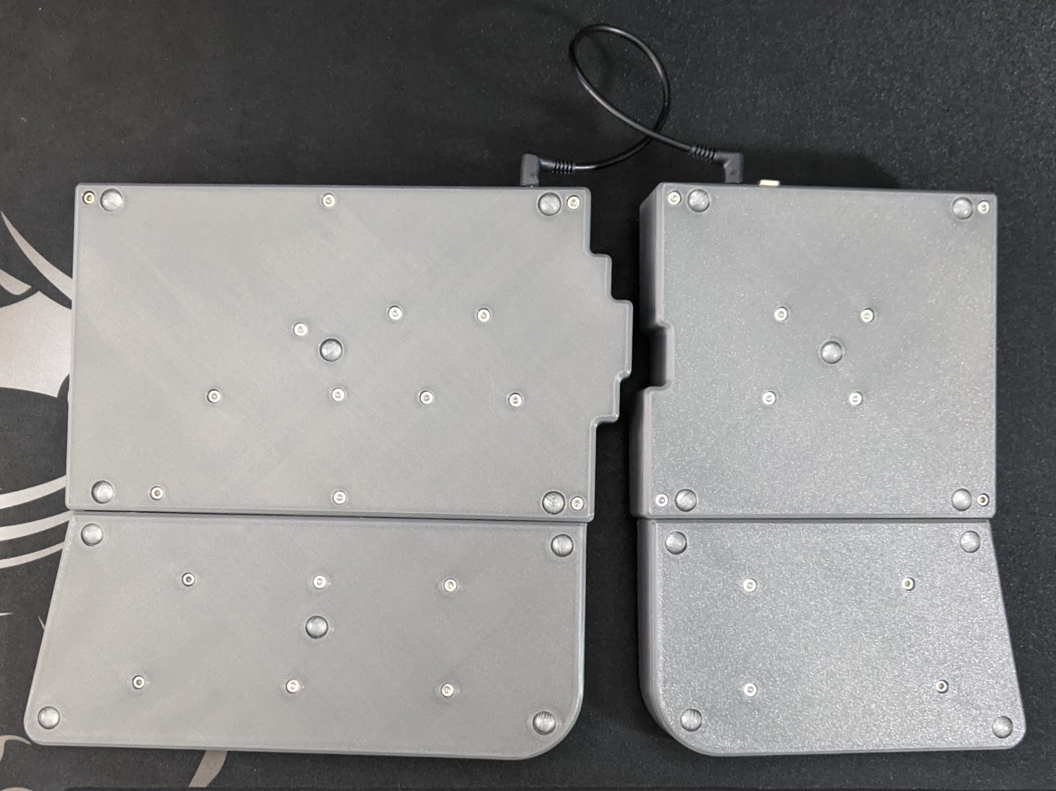
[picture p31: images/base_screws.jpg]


  I designed the foot inset holes to allow use of feet for grip and sound isolation but not protrude all the way to avoid adding height to the keyboard.  

Congrats!  You're done!  Happy Typing!  

Couple numbers for this build...

    347 solder points

    77.4 hour print time

Sounds like a lot and it is but if you build this, you will be stoked at the result and your efforts put in to it won't be in vain... least it was not for me.  This is my daily driver now and I use it all day long at work and afterwards.  I've built this four times now.  Stoked with the results of each build.

### My personal build

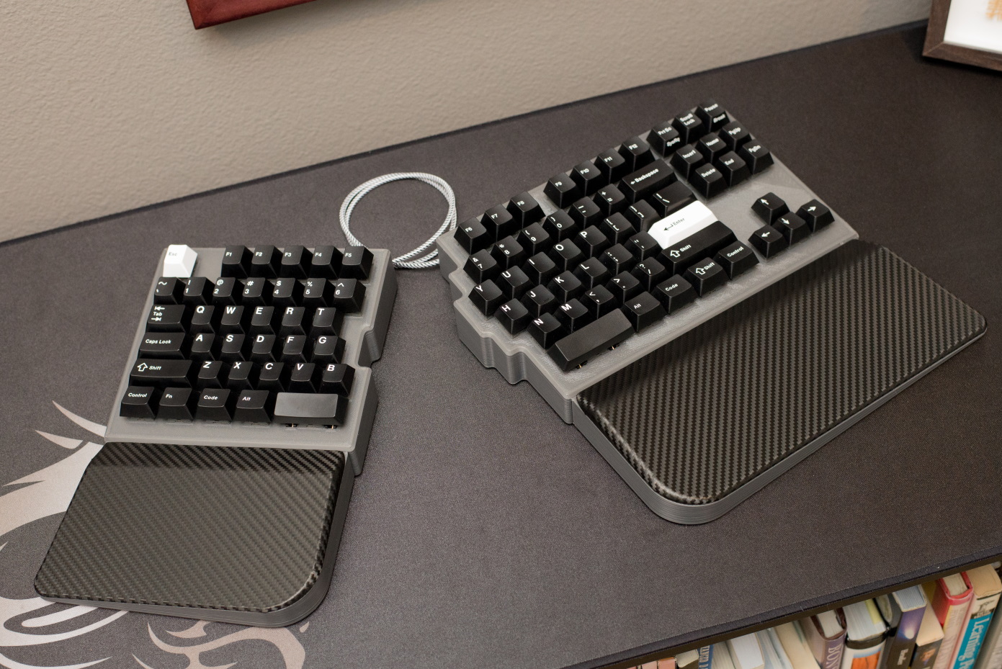
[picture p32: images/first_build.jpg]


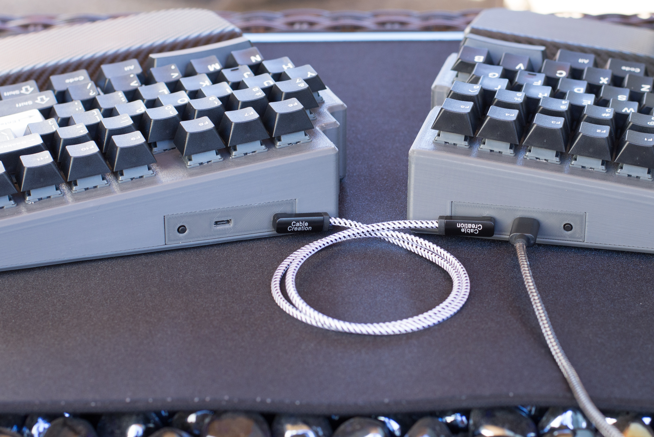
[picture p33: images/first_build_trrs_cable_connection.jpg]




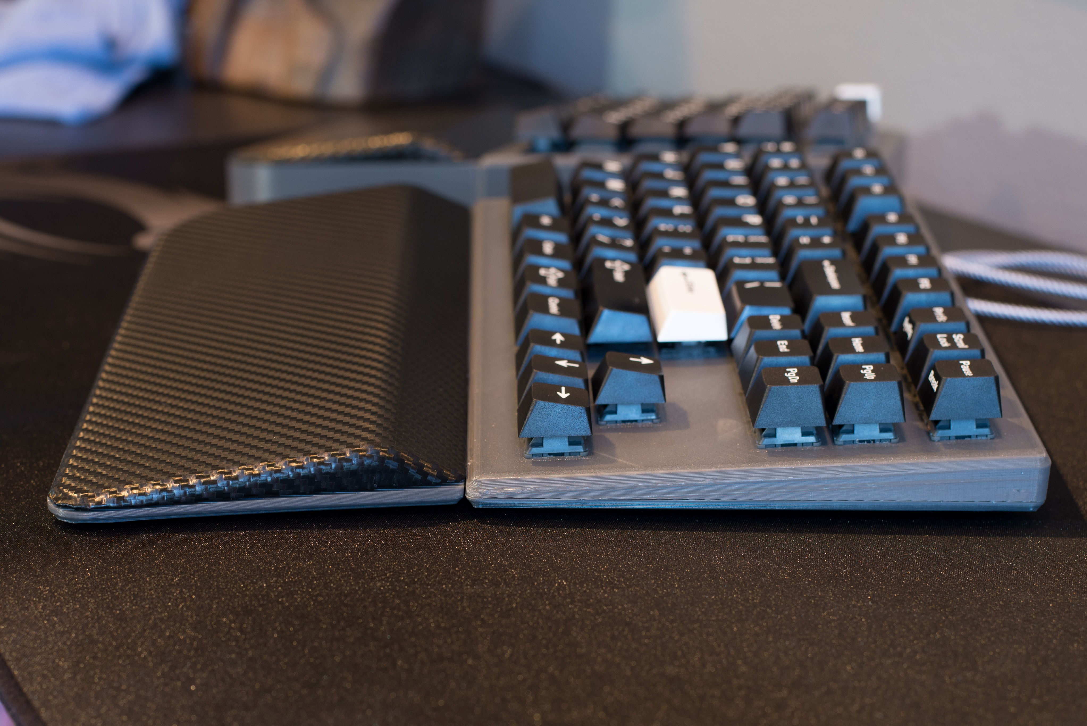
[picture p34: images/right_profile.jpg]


### My personal build main hardware

## Latest build - monochrome scheme (my favorite scheme)
  

Filament - [ERYONE Matte Black PLA](https://www.amazon.com/ERYONE-Filament-1-75mm-Printer-2-2LBS/dp/B08HX1XF55/)  
Key switches - [Gateron Ink V2 Linear Switches - Black](https://1upkeyboards.com/shop/switches/set-packs/gateron-ink-switches/)  
Stabilizers - [Durock](https://www.amazon.com/gp/product/B096JVL2MQ/)  
Keycaps - [AKKO White on Black ASA Profile PBT Double-shot](https://en.akkogear.com/product/white-on-black-keycap-set-158-key/)  
Car wrap vinyl - [3m Black Shadow](https://metrorestyling.com/products/3m-2080-shadow-black-textured-vinyl-wrap-sb12)  
TRS Cable - [CableCreation 1.5ft](https://www.amazon.com/gp/product/B01K3WYJBK/)  
USB-C Cable / magnetic disconnect -  [NetDot Gen7 Magnetic Charging Cable](https://www.amazon.com/NetDot-Braided-Magnetic-Charging-Compatible/dp/B07LBG1DFQ/)
Micro USB Cable / magnetic disconnect - [NetDot Gen7 Magnetic Charging Cable](https://www.amazon.com/gp/product/B01MZ634EJ/)  

## Carbon scheme
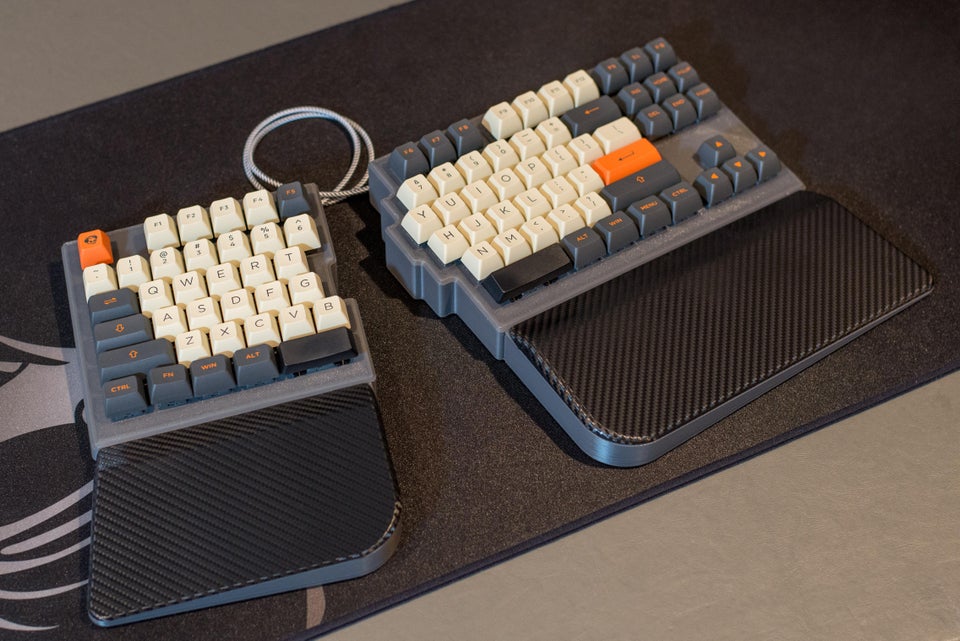
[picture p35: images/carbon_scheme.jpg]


Filament - [SUNLU Grey PETG](https://www.amazon.com/gp/product/B07Y5TCH9V/)  
Key switches - [Alpaca Linear](https://www.primekb.com/products/alpaca-linears?variant=37633188855971)  
Stabilizers - [Durock](https://www.amazon.com/gp/product/B096JVL2MQ/)  
Keycaps - [AKKO Carbon Retro](https://www.amazon.com/EPOMAKER-Double-Shot-Mechanical-Keyboard-Replacement/dp/B08XJSFTCB)  
Car wrap vinyl - [3m Black Carbon Fiber](https://www.ebay.com/itm/172810319316)  
TRS Cable - [CableCreation 1.5ft](https://www.amazon.com/gp/product/B01K3WYJBK/)  
USB Cable / magnetic disconnect - [NetDot Gen7 Magnetic Charging Cable](https://www.amazon.com/gp/product/B01MZ634EJ/)  

### My Tools
3D Printer - [Prusa MK3s](https://shop.prusa3d.com/en/3d-printers/180-original-prusa-i3-mk3s-kit.html)  
Soldering Iron - [Hakko FX888D](https://www.amazon.com/Hakko-FX888D-23BY-Digital-Soldering-Station/dp/B00ANZRT4M/)  
Solder - [Kester 24-6337-0010](https://www.amazon.com/gp/product/B00068IJWC/)  
Side Cutter - [IGAN-170](https://www.amazon.com/gp/product/B07GR7QF63/)  
Adjustable Wire Stripper - [Jonard Tools WS-5](https://www.amazon.com/Jonard-Tools-Adjustable-Stripper-10-30AWG/dp/B00WJPRKIY/)  
Machine Vice - [3d Printed Machine Vice](https://www.thingiverse.com/thing:2064269)

### GMK Info
See the [build environment setup](https://docs.qmk.fm/#/getting_started_build_tools) and the [make instructions](https://docs.qmk.fm/#/getting_started_make_guide) for more information.  

Brand new to QMK? Start with the [Complete Newbs Guide](https://docs.qmk.fm/#/newbs).  

[QMK GitHub](https://github.com/qmk/qmk_firmware)

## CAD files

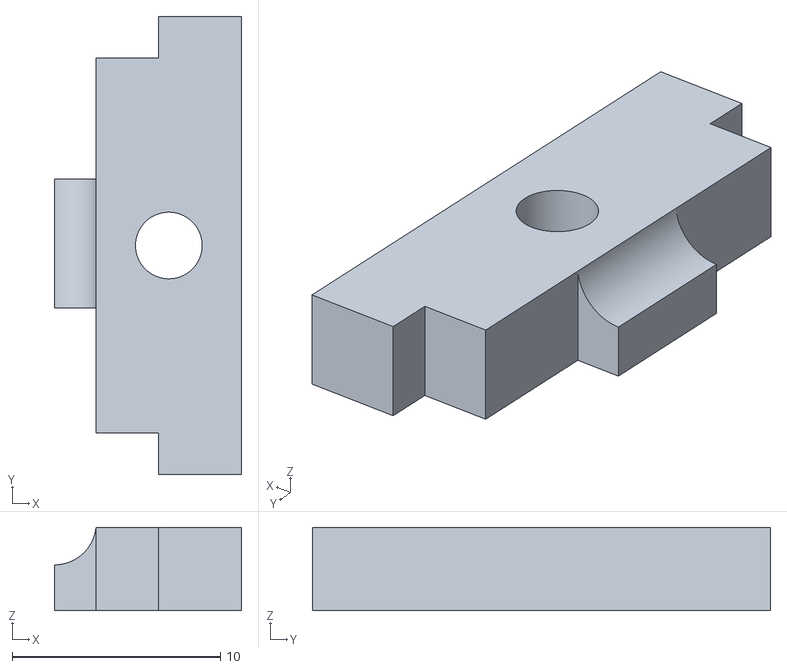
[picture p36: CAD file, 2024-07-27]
3d_printing_stl_files/split89_arduino_brace_usbc.stl
9.00 x 22.0 x 4.00

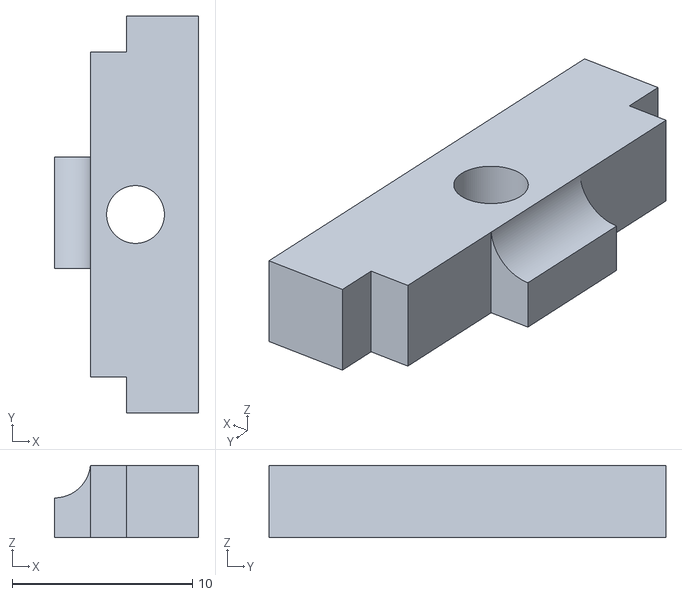
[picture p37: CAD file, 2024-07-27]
3d_printing_stl_files/split89_arduino_brace_microusb.stl
8.00 x 22.0 x 4.00

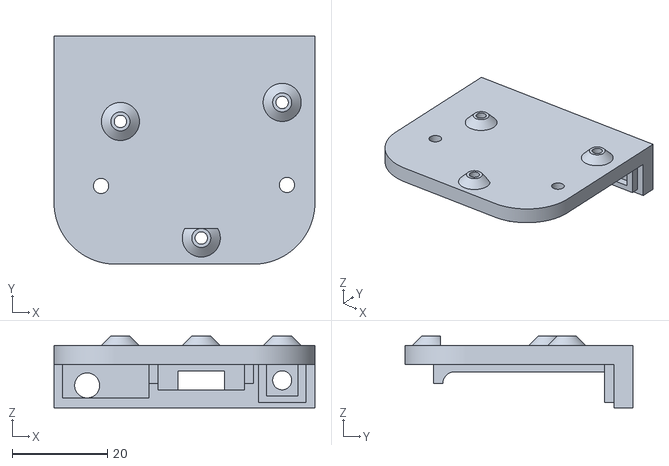
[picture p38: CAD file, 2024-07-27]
3d_printing_stl_files/split89_electronics_plate_usbc_right.stl
54.9 x 48.0 x 15.1

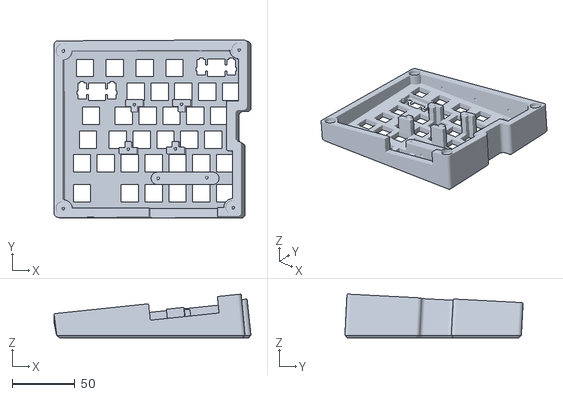
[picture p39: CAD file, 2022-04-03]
3d_printing_stl_files/split89_left_body.stl
157.3 x 142.3 x 34.8

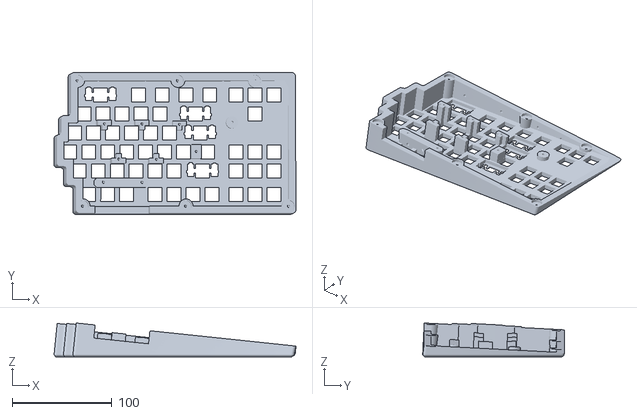
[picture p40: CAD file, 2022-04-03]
3d_printing_stl_files/split89_right_body.stl
242.8 x 142.2 x 33.9

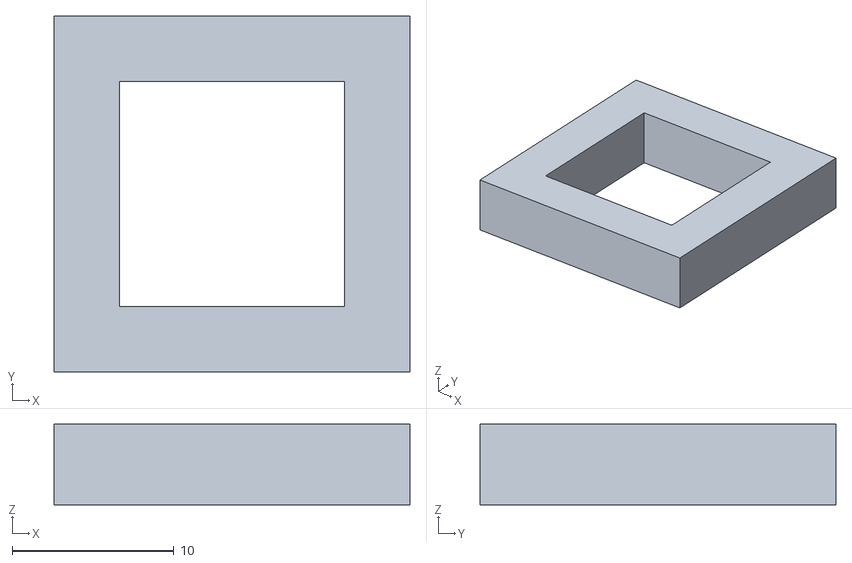
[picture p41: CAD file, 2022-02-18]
3d_printing_stl_files/split89_keyhole_test_print.stl
22.0 x 22.0 x 5.00

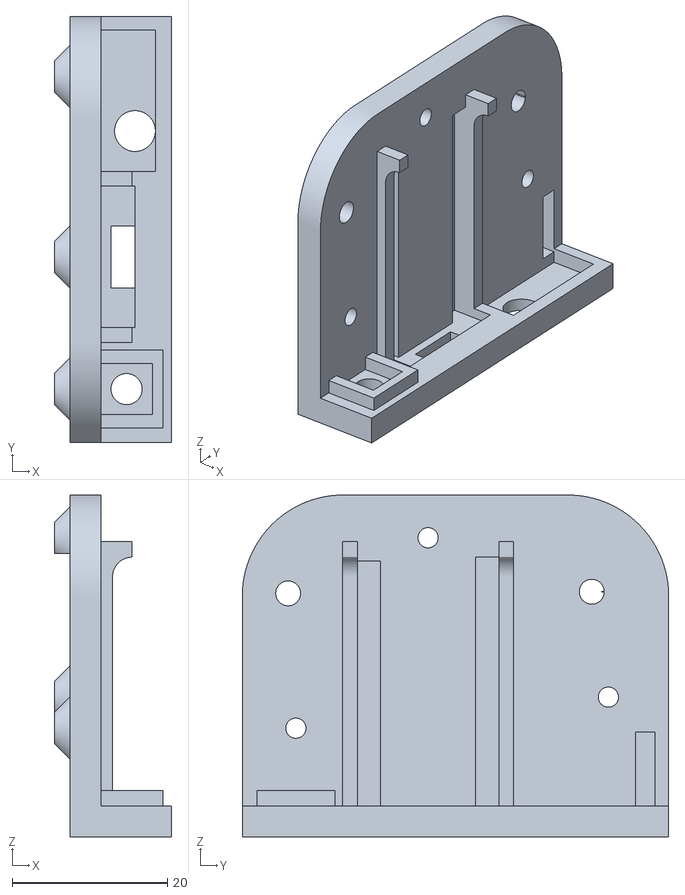
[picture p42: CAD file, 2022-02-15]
3d_printing_stl_files/split89_electronics_plate_microusb_left.stl
15.1 x 54.9 x 44.0

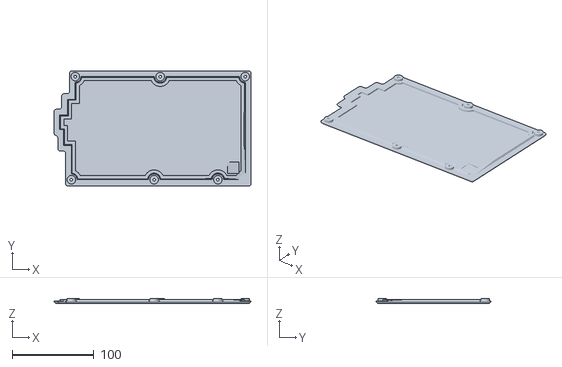
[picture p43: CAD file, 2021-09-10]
3d_printing_stl_files/split89_right_body_base_no_pillar.stl
240.7 x 140.8 x 5.80

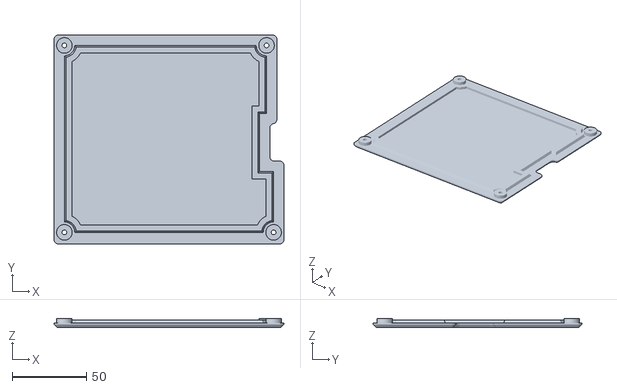
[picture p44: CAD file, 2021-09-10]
3d_printing_stl_files/split89_left_body_base_no_pillar.stl
155.1 x 140.8 x 5.80

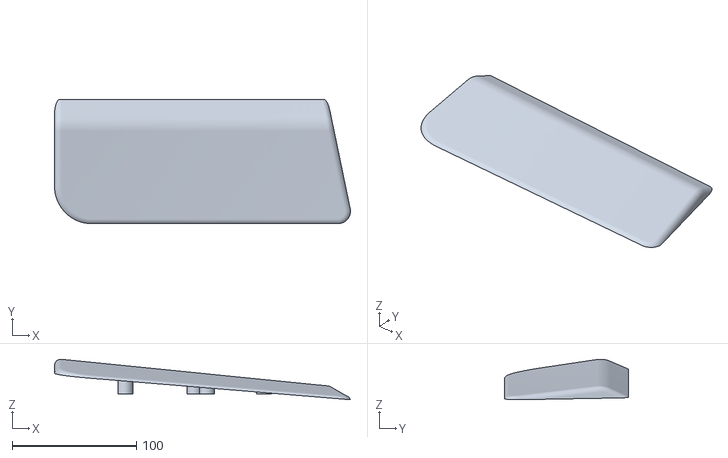
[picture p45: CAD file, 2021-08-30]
3d_printing_stl_files/split89_right_wrist_pad.stl
238.2 x 100.0 x 32.6

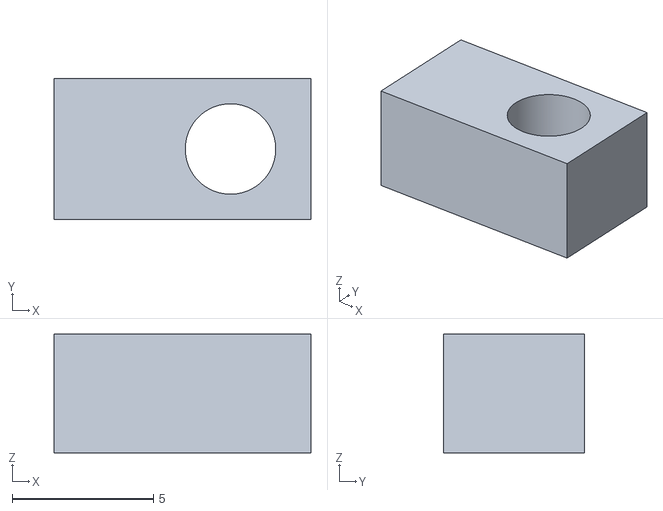
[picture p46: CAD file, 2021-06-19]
3d_printing_stl_files/split89_reset_button_brace.stl
9.10 x 5.00 x 4.20

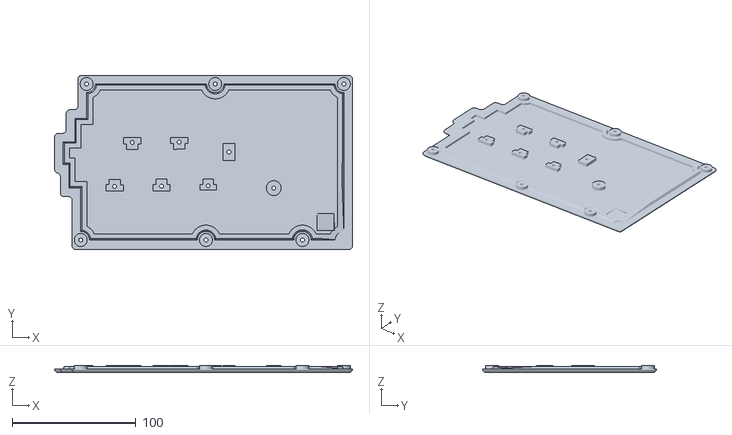
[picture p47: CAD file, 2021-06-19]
3d_printing_stl_files/split89_right_body_base.stl
240.7 x 140.8 x 6.00

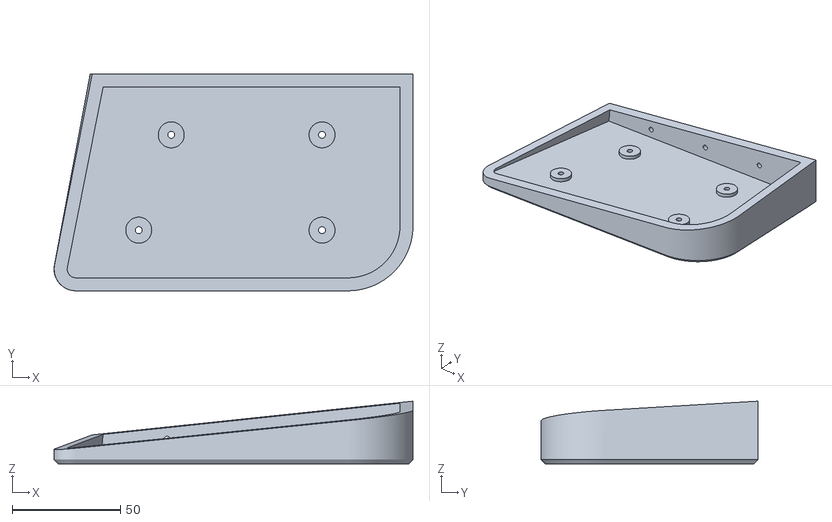
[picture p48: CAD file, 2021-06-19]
3d_printing_stl_files/split89_left_wrist_base.stl
165.7 x 100.0 x 28.9

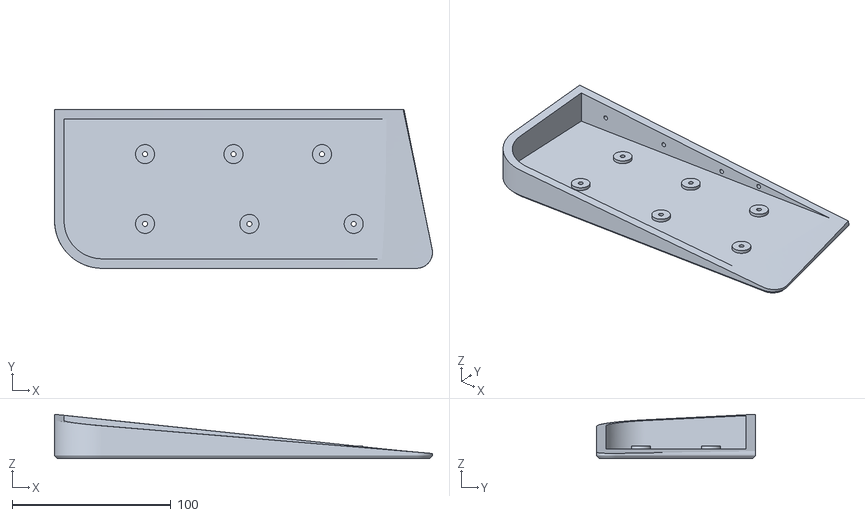
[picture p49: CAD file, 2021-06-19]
3d_printing_stl_files/split89_right_wrist_base.stl
238.3 x 100.0 x 28.0

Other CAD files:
3d_printing_stl_files/split89_electronics_plate_usbc_left.stl
3d_printing_stl_files/split89_electronics_plate_microusb_right.stl
3d_printing_stl_files/split89_left_wrist_pad.stl
3d_printing_stl_files/split89_left_body_base.stl
3d_printing_stl_files/split89_trrs_jack_brace.stl

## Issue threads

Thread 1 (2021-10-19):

Keys shifted from QMK Configurator

rmont881, 2021-10-19:
When flashing the firmware made from the QMK Configurator, all of they keys are shifted over as if the columns are misconfigured. For example, the backspace key is actually the =, the insert key is the backspace, etc. This happens on both the left and the right side. The rows seem to be right, the columns seem to be shifted left by one.

Tested both in a wired left hand keyboard, and flashing to an arduino and manually connecting the pins relating to the rows/columns.

jurassic73, 2021-11-04:
I got the keyboard mapping corrected except I missed an update in the configurator mapped layout(separate repositories).  When you go to qmk configurator now and bring up the split89 layout, in the lower left corner the control key is configured as a shift key. If you change that to left control key and download the firmware you'll be good.

I submitted a pull request to fix that last key map bit.

Any chance you documented your build online? You're the first person to reach out it has built my keyboard design.  Would be really need to see pictures of it. 🙂

rmont881, 2021-11-04:
Sweet, I'll give it a shot! I was helping with the build when we ran into this and that one wasn't documented, but I am building one myself right now I'll get this one documented and posted somewhere. Thanks for responding so quick with the hex file to unblock the build, that was super helpful!

jurassic73, 2021-11-04:
Thanks for the patience and feedback!  I'm stoked folks are building this after putting it out there.  :)  I built three myself.  Gave one to my brother and we're both using them now as daily drivers.  Having you, as another builder, go through the process is helping me refine any opportunities in the documentation for future builders to have a smoother experience.  If you see anything else, please let me know.  Thanks.

rmont881, 2021-11-04:
On that, in your write up you never posted where you get your headphone jack breakout boards. I couldn't find anything that looked similar so we got these(linked below) and then modeled a really simple backing brace and drilled the hole out to fit. I can upload the STL for it as well to give more options for anyone building in the future as well. Other than that part, everything else on this case was way nicer to build than any of the other 3d printed keyboards I've made.

https://www.amazon.com/dp/B008SNZUYC?psc=1&ref=ppx_yo2_dt_b_product_details

jurassic73, 2021-11-04:
Ah shoot... that was added later on.  Good catch and sorry.

(2) Tactile Micro vertical mount switch (6mmx6mmx8mm total height / 4.5mm button height) - Aliexpress

https://www.aliexpress.com/item/4000543708838.html?spm=a2g0s.9042311.0.0.27424c4dCLLkyk

jurassic73, 2021-11-04:
Thanks for the kind words... this design was tweaked a bit as I built it and saw opportunities.  I put the dimensions in there too for the button.

jurassic73, 2021-11-04:
(2) TRRS breakout boards

https://www.aliexpress.com/wholesale?SearchText=trrs+audio+socket+breakout

jurassic73, 2021-11-04:
Added an Amazon link as well for the TRRS boards.  Thanks.

jurassic73, 2021-11-04:
Default keymap has been updated in the QMK configurator to generate firmware and confirmed as working.  Thanks for the feedback.

pulsar256, 2023-01-06:
Ran into the issue of shifted columns with the official QMK configurator build today. Seems to be still an issue. HEX file embedded in this repo does not exhibit the behaviour.

Shall I open a PR with notes that in the README? I might also add a couple of lines about the flashing process.

jurassic73, 2023-01-06:
Someone changed my config. This was working a month or so ago. It's clear
that someone updated something to shift the keys. A for example is now on
Caps Lock.

https://config.qmk.fm/#/handwired/split89/LAYOUT

On Fri, Jan 6, 2023 at 5:26 AM Paul Rogalinski-Pinter <
***@***.***> wrote:

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

pulsar256, 2023-01-06:
> Would love to see your build added here: https://www.printables.com/model/75599-split89/comments :)

will do! Had to tweak the MCU mounts a bit as well (pro micro with usb-c, dimensions of the jack breakout slightly off), will go into details in the comment.

jurassic73, 2023-01-06:
>

Great - thanks!

Working with the QMK devs on fixing up my keyboard layout. Needs some retooling to adhere to their standards correctly. It worked but something was not correct in such a way that my stuff broke with some cleanup they were doing. They provided guidance with how to fix so I'll work on this this weekend. Least you can move ahead with the hex file up there currently to get your keyboard going.

Closed 2021-11-04.

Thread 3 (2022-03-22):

Low Profile Keys?

vkhurana, 2022-03-22:
Would it be possible to get the F3D/Source files for the housing? It would be useful to adapt the board for low-profile keys:
https://hexus.net/tech/news/peripherals/114314-cherry-announces-mx-low-profile-rgb-key-switches/

The dimensions of low profile keys is slightly smaller than regular full-profile keys:
```
... dimensions of 11.9 x 15.0 x 15.0mm (H x W x D). For the record a conventional MX switch measures 18.5 x 15.6 x 15.6mm (H x W x D) ...
```

I'd be happy to give it a shot and update the stls for low-profile keys.

jurassic73, 2022-04-03:
They still fit in a 14mm x 14mm hole.  The overall dimension changed but not the hole size requirement.  There should be no adjustment required to use those. :)

vkhurana, 2022-04-03:
Thank you! I'll print the reference square and give it a shot.

Closed 2022-04-03.

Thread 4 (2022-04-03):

Left body requires supports for bolt pillars?

dgurchenkov, 2022-04-03:
Hi,

First, thank you for putting together this keyboard and instructions. This is an awesome project!

When trying to follow the instructions and print/build/assemble the keyboard, I seem to have found an issue that may require either updating the printing instructions, or perhaps some change to one or more .stl files. I am a newbie so this may just be my misunderstanding -- please feel free to close this issue.

The printing instructions in readme.md indicate that no supports need to be added when printing, with the exception of wrist pads.
However, the split89_left_body.stl has elements (bolt pillars) that hang down from the main body but do not touch the base plate. "As-is" slicing in Cura produces a gcode file that is not printable, because the printer then tries to start printing those bold pillars "from the air" at some distance from the base plate, and the filament has nothing to adhere to. Please see an attached screenshot where I circled (in grey) the four columns in left_body.stl that do not touch the base plate.

Reproduction steps:
* I use Ender-3 v2 printer, Cura v 4.13.1, printing with generic PLA filament
* Open split89_left_body.stl in Cura, do not enable supports, slice, send directly to the printer.
* The bolt pillars in the middle of the body do not get printed. Extruder extracts the filament that hangs in the air.
* (I have not yet attempted to complete the print - stopped after a few layers).

I'm currently attempting to print the left body with supports automatically generated in Cura, but that obviously adds a lot of extra material to be printed, so I thought I'd ask you if that was the design intent of that body part.

Thanks for looking at this, and again, please feel free to close if this is just a user mistake.

Thanks,

Denis.
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

dgurchenkov, 2022-04-03:
Perhaps a simpler explanation is that this piece should be printed upside down?

jurassic73, 2022-04-03:
My bad on this!  I've corrected these and uploaded them.  I swear I uploaded these in their print orientation.  You are correct.  The top surface is face down when printing.  Thanks for letting me know and sorry for any waste time.

dgurchenkov, 2022-04-04:
Thanks! Prints perfectly now!

Closed 2022-04-03.

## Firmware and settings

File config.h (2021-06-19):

/*
Copyright 2021 jurassic73

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
You should have received a copy of the GNU General Public License
along with this program.  If not, see <http://www.gnu.org/licenses/>.
*/

#pragma once

#include "config_common.h"

/* USB Device descriptor parameter */
#define VENDOR_ID    0xFEED
#define PRODUCT_ID   0x0000
#define DEVICE_VER   0x0001
#define MANUFACTURER jurassic73
#define PRODUCT      split89

/*
 * Keyboard Matrix Assignments
 *
 * Change this to how you wired your keyboard
 * COLS: AVR pins used for columns, left to right
 * ROWS: AVR pins used for rows, top to bottom
 * DIODE_DIRECTION: COL2ROW = COL = Anode (+), ROW = Cathode (-, marked on diode)
 *                  ROW2COL = ROW = Anode (+), COL = Cathode (-, marked on diode)
 *
 */

/* key matrix size
ROWS = total count of rows for both sides - this is broken out accordingly in split.h
COLS = number of cols per side which curently needs to be equal so there are blank columns for the left side in the split89.h file
 */
#define MATRIX_ROWS 12
#define MATRIX_COLS 10

/* Left side matrix */
#define MATRIX_ROW_PINS { F6, F7, B1, B3, B2, B6 }
#define MATRIX_COL_PINS { F5, F4, B5, B4, E6, D7, C6, D4, D2, D3 }
/* Right side matrix */
#define MATRIX_ROW_PINS_RIGHT { F6, F7, B1, B3, B2, B6 }
#define MATRIX_COL_PINS_RIGHT { F5, F4, B5, B4, E6, D7, C6, D4, D2, D3 }

/* this will be tied to high (VCC with a 2k to 10k resistor) on the left keyboard half and tied to low (GND using a wire jumper only) on the right keyboard half.  This allows a user to plug in a USB cable to either side and function correctly with or without a TRS/TRRS cable with a single hex file. */
#define SPLIT_HAND_PIN D1

/* COL2ROW, ROW2COL */
#define DIODE_DIRECTION COL2ROW

/* handedness */
/*
 * Split Keyboard specific options, make sure you have 'SPLIT_KEYBOARD = yes' in your rules.mk, and define SOFT_SERIAL_PIN.
 */
#define SOFT_SERIAL_PIN D0  // or D1, D2, D3, E6
#define USE_SERIAL

//#define LED_NUM_LOCK_PIN B0
//#define LED_CAPS_LOCK_PIN B1
//#define LED_SCROLL_LOCK_PIN B2
//#define LED_COMPOSE_PIN B3
//#define LED_KANA_PIN B4

//#define BACKLIGHT_PIN B7
//#define BACKLIGHT_LEVELS 3
//#define BACKLIGHT_BREATHING

//#define RGB_DI_PIN E2
//#ifdef RGB_DI_PIN
//#    define RGBLED_NUM 16
//#    define RGBLIGHT_HUE_STEP 8
//#    define RGBLIGHT_SAT_STEP 8
//#    define RGBLIGHT_VAL_STEP 8
//#    define RGBLIGHT_LIMIT_VAL 255 /* The maximum brightness level */
//#    define RGBLIGHT_SLEEP  /* If defined, the RGB lighting will be switched off when the host goes to sleep */
/*== all animations enable ==*/
//#    define RGBLIGHT_ANIMATIONS
/*== or choose animations ==*/
//#    define RGBLIGHT_EFFECT_BREATHING
//#    define RGBLIGHT_EFFECT_RAINBOW_MOOD
//#    define RGBLIGHT_EFFECT_RAINBOW_SWIRL
//#    define RGBLIGHT_EFFECT_SNAKE
//#    define RGBLIGHT_EFFECT_KNIGHT
//#    define RGBLIGHT_EFFECT_CHRISTMAS
//#    define RGBLIGHT_EFFECT_STATIC_GRADIENT
//#    define RGBLIGHT_EFFECT_RGB_TEST
//#    define RGBLIGHT_EFFECT_ALTERNATING
/*== customize breathing effect ==*/
/*==== (DEFAULT) use fixed table instead of exp() and sin() ====*/
//#    define RGBLIGHT_BREATHE_TABLE_SIZE 256      // 256(default) or 128 or 64
/*==== use exp() and sin() ====*/
//#    define RGBLIGHT_EFFECT_BREATHE_CENTER 1.85  // 1 to 2.7
//#    define RGBLIGHT_EFFECT_BREATHE_MAX    255   // 0 to 255
//#endif

/* Debounce reduces chatter (unintended double-presses) - set 0 if debouncing is not needed */
#define DEBOUNCE 5

/* define if matrix has ghost (lacks anti-ghosting diodes) */
//#define MATRIX_HAS_GHOST

/* Mechanical locking support. Use KC_LCAP, KC_LNUM or KC_LSCR instead in keymap */
#define LOCKING_SUPPORT_ENABLE
/* Locking resynchronize hack */
#define LOCKING_RESYNC_ENABLE

/* If defined, GRAVE_ESC will always act as ESC when CTRL is held.
 * This is useful for the Windows task manager shortcut (ctrl+shift+esc).
 */
//#define GRAVE_ESC_CTRL_OVERRIDE

/*
 * Force NKRO
 *
 * Force NKRO (nKey Rollover) to be enabled by default, regardless of the saved
 * state in the bootmagic EEPROM settings. (Note that NKRO must be enabled in the
 * makefile for this to work.)
 *
 * If forced on, NKRO can be disabled via magic key (default = LShift+RShift+N)
 * until the next keyboard reset.
 *
 * NKRO may prevent your keystrokes from being detected in the BIOS, but it is
 * fully operational during normal computer usage.
 *
 * For a less heavy-handed approach, enable NKRO via magic key (LShift+RShift+N)
 * or via bootmagic (hold SPACE+N while plugging in the keyboard). Once set by
 * bootmagic, NKRO mode will always be enabled until it is toggled again during a
 * power-up.
 *
 */
//#define FORCE_NKRO

/*
 * Feature disable options
 *  These options are also useful to firmware size reduction.
 */

/* disable debug print */
//#define NO_DEBUG

/* disable print */
//#define NO_PRINT

/* disable action features */
//#define NO_ACTION_LAYER
//#define NO_ACTION_TAPPING
//#define NO_ACTION_ONESHOT
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

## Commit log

2021-06-20 Adjusted stl orientation
    Adjusted stl orientation to suggested print orientation.
    [split89_electronics_plate_left.stl, split89_electronics_plate_right.stl, split89_left_body.stl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]
2021-08-30 Update split89_right_wrist_pad.stl
    Corrected screw hole depth in one hole was was 6mm too shallow.
    [split89_right_wrist_pad.stl]
2021-09-10 Added base plates without pillars
    These base plates allow the top surface to decouple from the bottom surface and create a deeper sound when typing.
    [split89_left_body_base_no_pillar.stl, split89_right_body_base_no_pillar.stl]
2021-09-13 Update split89_left_body.stl
    Corrected single hole size from 10.5mm to 11mm for tolerance to match other holes. Base cover will still install but tightly on older 10.5mm size.
    [split89_left_body.stl]
2021-09-14 Opened up USB port slightly to match spec.
    [split89_electronics_plate_left.stl, split89_electronics_plate_right.stl]
2021-09-17 Reoriented stls for quicker slicing.
    [split89_electronics_plate_left.stl, split89_electronics_plate_right.stl, split89_left_body.stl]
2022-02-07 Adjusted stab holes by .3mm
    Stabs snap into place a bit easier.
    [split89_left_body.stl, split89_right_body.stl]
2022-02-07 Adjusted stab holes
    Adjusted stab holes to decrease depth at locking tab.
    [split89_left_body.stl, split89_right_body.stl]
2022-02-07 Reoriented bodies for quicker slicing.
    [split89_left_body.stl, split89_right_body.stl]
2022-02-15 Electronics plate adjustment
    Narrowed boards by .2mm on center for easier fitment. The old stls worked fine for my builds but were a touch to snug during install.
    [split89_electronics_plate_left.stl, split89_electronics_plate_right.stl]
2022-02-18 Create split89_keyhole_test_print.stl
    Adding test print piece for ensuring good fit of keyswitches with no elephant foot.
    [split89_keyhole_test_print.stl]
2022-02-18 Update readme.md
    Added model for keyswitch hole test.
2022-02-24 Adjusted stab holes
    Shifted .3 stab adjustment .15 to center stab correctly. Verified with print.
    [split89_left_body.stl, split89_right_body.stl]
2022-02-24 Further refinement for stab fitment.
    [split89_left_body.stl, split89_right_body.stl]
2022-04-03 Corrected body orientationl
    [split89_left_body.stl, split89_right_body.stl]
2023-01-10 Update readme.md
    Printing resource subreddit added.
2024-07-27 Add files via upload
    Added USBC plates.
    [split89_electronics_plate_usbc_left.stl, split89_electronics_plate_usbc_right.stl, split89_usbc_electronic_plates.stl]

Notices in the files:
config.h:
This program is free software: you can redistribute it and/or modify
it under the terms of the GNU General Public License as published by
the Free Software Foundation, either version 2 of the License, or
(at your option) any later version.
